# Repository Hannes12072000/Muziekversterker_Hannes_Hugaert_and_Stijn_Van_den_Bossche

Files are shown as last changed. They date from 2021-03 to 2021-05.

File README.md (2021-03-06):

# Muziekversterker_Hannes_Hugaert_and_Stijn_Van_den_bossche
 
onderwerp:  Touch muziekversterker
naam:   Hannes Hugaert & Stijn Van den bossche

Korte beschrijving:
Wij gaan een muziekversterker maken die voorzien is van 2 channels en een microfoon. Op deze versterker kunnen we de tonen regelen (treble, medium en bass) maar we kunnen ook het volume regelen. Onze sliders zijn geen gewone mechanische sliders, we voorzien touchpads als sliders. Om feedback over het volume en de tonen te geven, voorzien we ledjes naast de touchpads om het huidige niveau weer te geven.

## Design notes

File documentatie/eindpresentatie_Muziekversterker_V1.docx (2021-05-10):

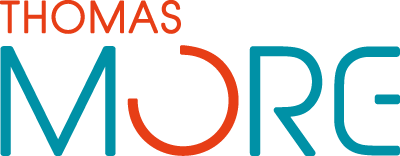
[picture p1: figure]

Thomas More

Campus De Nayer

Jan De Nayerlaan 5

2860 Sint-Katelijne-Waver

Tel. (015) 31 69 44

Practice Enterprise Electronics

Schooljaar 2020-2021

NAAM: Hannes Hugaert & Stijn Van den bossche

#### ONDERWERP: Muziekversterker

AFDELING: Elektronica – Embedded Hardware 2 | 2EE2

Elektronica – Embedded Software 2 |

# 1. Woord vooraf

Wij gaan een muziekversterker maken die voorzien is van 2 input-channels en een microfoon. Op deze versterker kunnen we de verschillende tonen regelen per kanaal (treble, medium en bass), alsook het volume van deze kanalen. Hier bovenop voorzien we ook een ‘balans’, om te regelen in welke mate beide kanalen worden doorgegeven, en ook een ‘master output’. Hiermee kiezen we het volume van het uiteindelijke uitgangssignaal. Onze sliders zijn niet de gewone, mechanische sliders die meestal aanwezig zijn op een mengpaneel, wij voorzien touchpads als sliders. Om ook het volume of de verschillende tonen te visualiseren, voorzien we ledjes naast de touchpads.

# 2. Hardware

## 1.1. Blokschema

Audio output: staat voor de luidsprekers die aan de uitgang komen, dezen moeten voorzien worden van een inwendige versterking omdat onze versterker amper stroom zal hebben aan de uitgang.

2 AUDIO inputs: Wij hebben ons mengpaneel voorzien van 2 inputkanalen waar wij muziek op kunnen laten spelen (via AUX).

Ook kunnen we op lijn 1 eventueel een microfoon steken, zodat over de muziek heen te praten is, indien gewenst.

5V DC: micro USB, dit is de voeding voor de versterker.

5V DC naar 3.3 V DC: dit is de naam van de component 173950336, het is een step-down die 5V omzet naar +3.3 V DC. Dit wordt gebruikt om de microcontroller en de capacitieve touchsensor te voeden.

Microcontroller: De gebruikte microcontroller is een STM32F411CEU7, om hiermee te communiceren wordt een st-link V2 gebruikt, zodat we deze kunnen programmeren. Onze Microcontroller is van de SMT32F4x familie en die wordt gevoed met 3.3V en we willen ook ongeveer 40 I/O. En onze heeft er 49 dus dat is zeer goed.

8-digit LED displaydrivers: deze chip heet MAX7219CNG+. Dit is een chip om 8 segment displays aan te sturen, wij gebruiken een ‘matrix’ van leds, waarvoor deze drivers ook te gebruiken zijn.

Dit hoort samen

LED’s: Dezen laten het huidig geselecteerde volume en de stand van de verschillende tonen zien. Er zijn 132 leds, om dit genoeg in detail weer te geven.

Capacitieve touchsensor: deze sensor heet de MTCH6301-I_ML, het leest capacitieve aanrakingen afkomstig van de touchpads, zet deze om naar coordinaten, en verstuurt deze via een I²C signaal. Deze waardes worden wel opnieuw geïnterpreteerd, aangezien de gebruikte touchpads niet allemaal samen staan, en het dus niet één compleet vlak is. We hebben ook gekozen voor capacitief omdat dat geen corrosie geeft op de sliders.

Dit hoort samen

Touchpads: dit zijn geleiders die op een print door middel van aanraking een capacitief signaal doorsturen. Deze touchpads dienen als sliders van het mengpaneel. Ze zijn zelf ontworpen, om hier een grote kost uit te sparen, en zelf de vorm en grootte te kunnen bepalen.

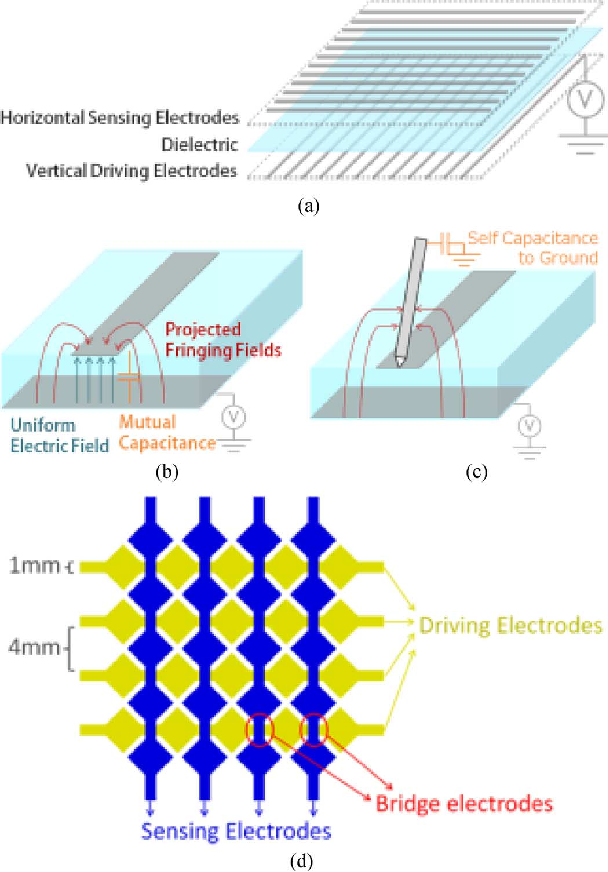
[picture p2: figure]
Figure 1 from An Analysis of Electrode Patterns in Capacitive Touch Screen Panels | Semantic Scholar

Digitale potentiometers: onze potentiometers hebben de naam AD5204BRUZ10-REEL7. Tijdens het kiezen hoe we de potentiometers zouden aansturen, bleek dat het makkelijker zou zijn om digitaal gestuurde potentiometers te werken, anders hadden we zelf mechanische sliders moeten voorzien, wat veel duurder ging uitkomen.

Versterking: We gebruiken de opamps LM324A. Ze vormen de basis van de versterkingcircuits.

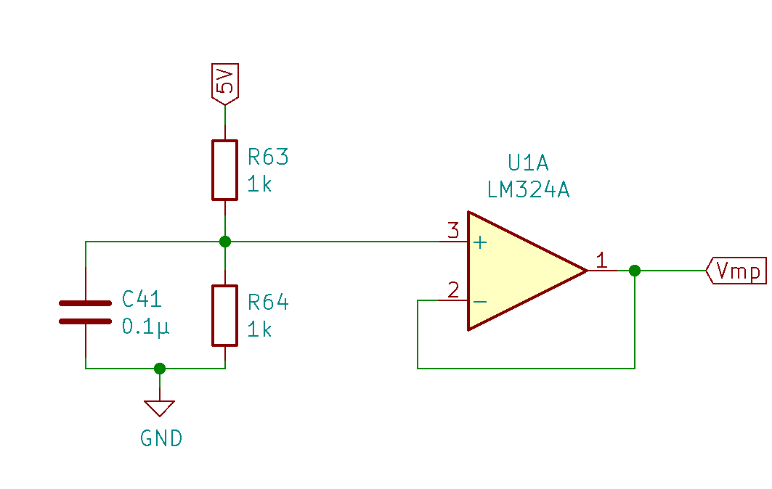
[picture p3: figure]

Virtuele grond: Omdat we problemen hadden met de potentiometers en zo in de schakeling hebben we een virtueel middelpunt moeten maken dit is aan de hand van een spanningsdeler een opamp.

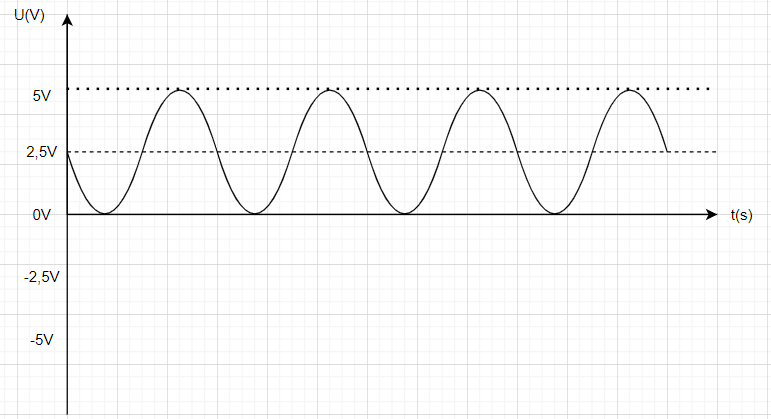
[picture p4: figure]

5V/2 =2,5V is dus gewoon een spanningsdeller gedeeld door 2 waardoor we gewoon twee gelijke weerstanden moeten nemen. De docent stelde ons voor om 1kΩ weerstanden te gebruiken.

We willen dat het nulpunt op 2,5 V ligt. Zodat we de opamps kunnen fluctueren tussen 0V en 5V. Zo hebben we zekerheden met het signaal en de potentiometers en dan kunnen we gewoon de 5V van de usb gebruiken wat heel handig. Anders moesten we de spanning verlagen van 5V naar 2,5V en ook naar -2,5V en dat gaat ons veel meer kosten dan dat we het middelpunt gaan verleggen. We blijven ook het zelfde uitgangssignaal horen.

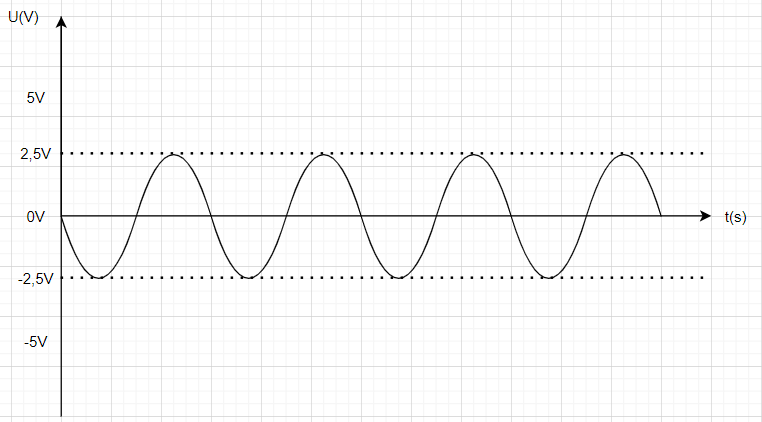
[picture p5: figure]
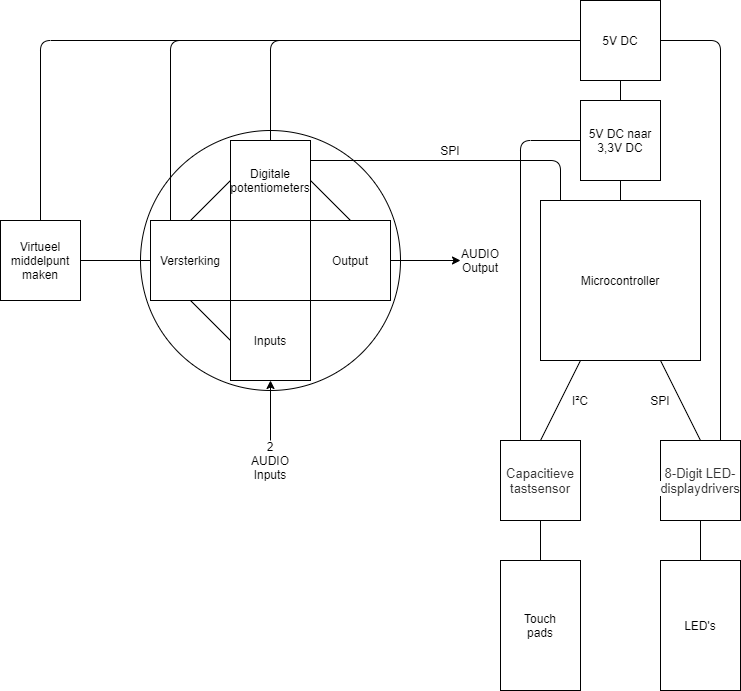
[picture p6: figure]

## 1.2. Schema

Touchpad: Dit is het symbool van onze sliders, deze hebbe zelf ontworpen om dat we deze wouden verwerken in onze PCB, hier hebbe we heel veel moeten voor opzoeken want zoe een raster van een slider moet aan een bepaalde afmetingen voldoen zodat het zeker voldoende afstand heeft van el vlakje en ook een deftige connectie kunt maken als je met je vinger op de touchpad komt.

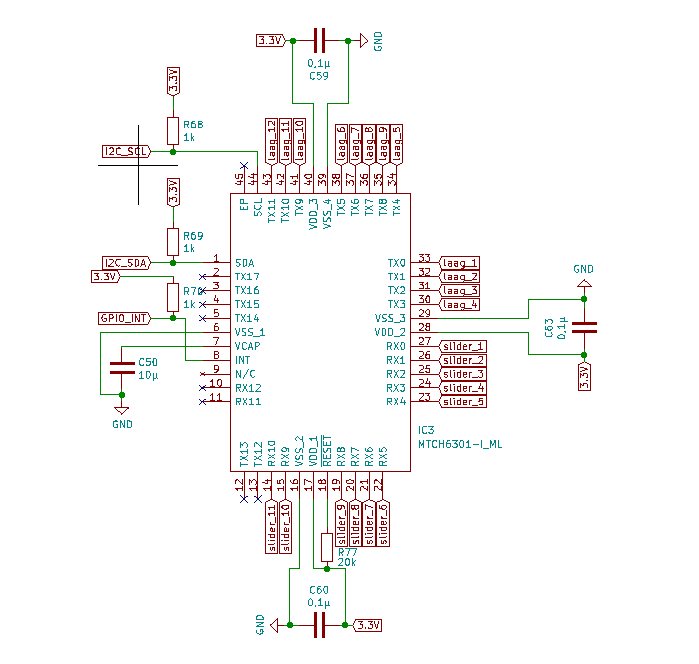
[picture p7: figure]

MTCH6301-I_ML: dit is de IC die de signalen op de touchpad’s uitleest en om zet in data die over I²C naar de microcontroller gaat.

Deze condensatoren zorgen er voor dat er geen storing op de 3.3V zit, zo blijf je een ongeveer een mooie rechte 3.3V hebben.

Als de interrupt van de microcontroller spanning verliest of de spanning is hoger dan 3.3V zorgt de pull up weerstand dat de nodige 3.3V aan de IC komt.

De RESET moet laag zijn om een zichzelf te resetten maar wij willen niet dat dat we deze chip resetten dus daarom zetten we ze aan de 3.3V zodat de chip zijn data niet verliest door de reset.

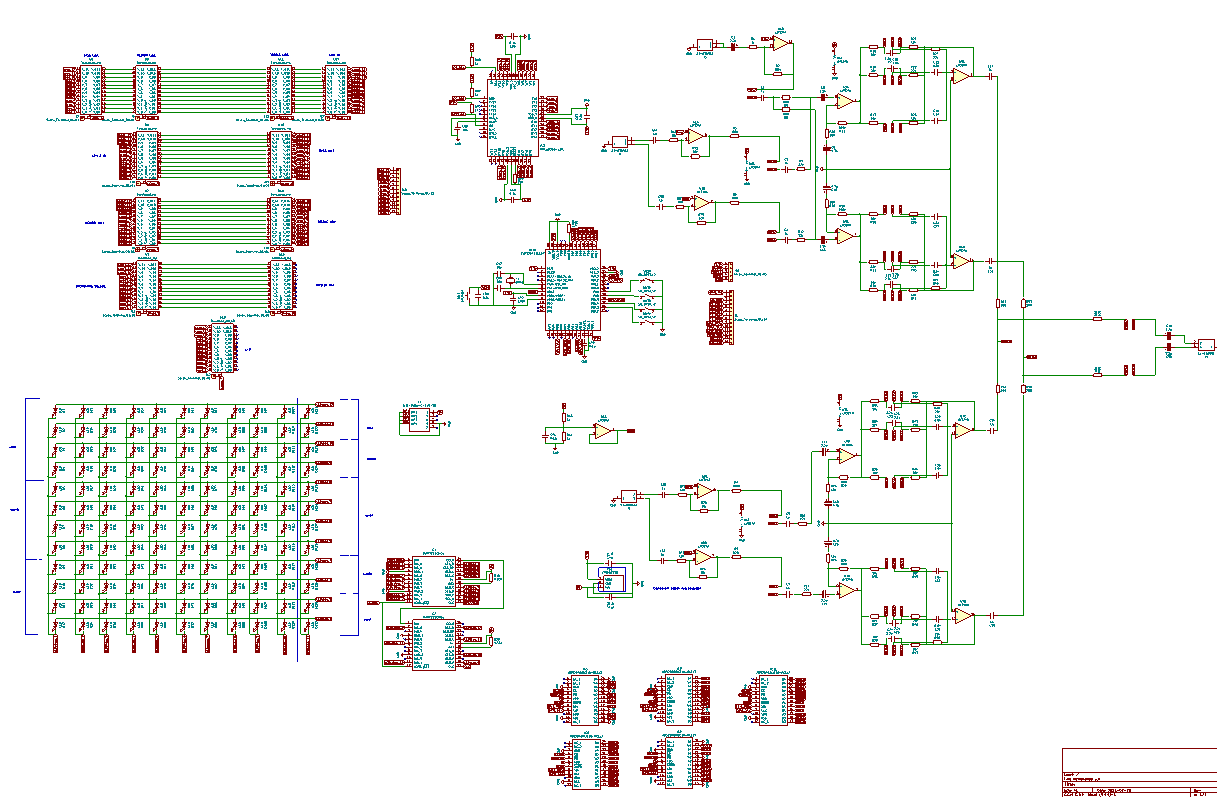
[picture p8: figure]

Micro usb

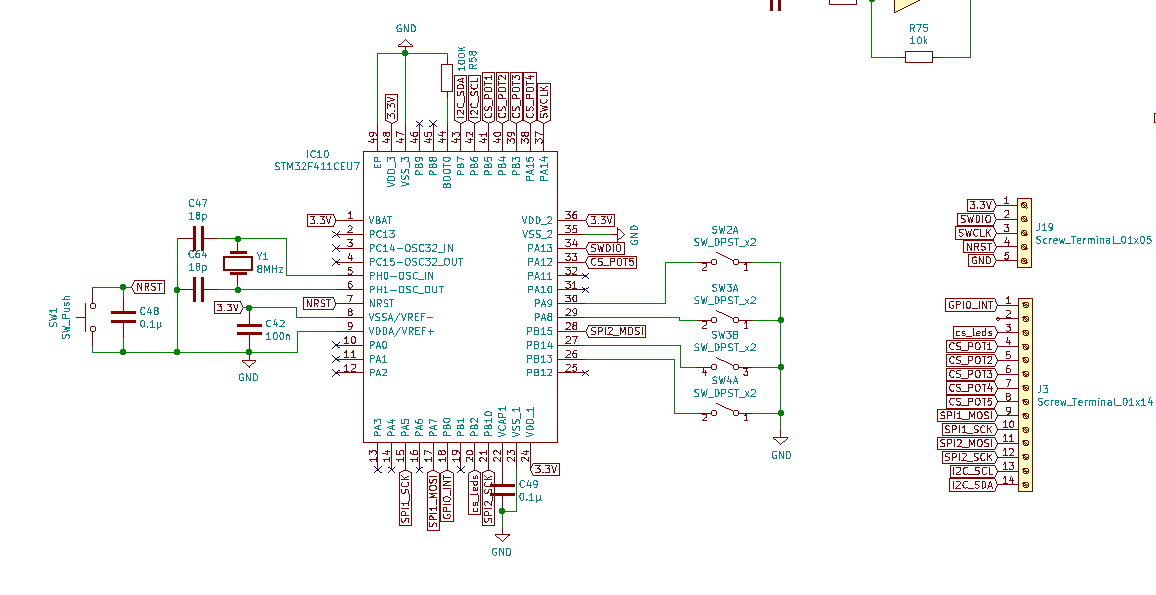
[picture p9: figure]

STM32F411CEU7: Deze microcontroller is voorzien van 512KB Flash en 128 KB RAM en is een ARM cortex die op 32 bit werkt. Deze microcontroller is voorzien van 49 pinnen wat ruim genoeg is voor onze uitwerking. Deze microcontroller moet gevoed worden op een spanning tussen 1.7 en 3.6 dus hebben we gekozen voor het midden ongeveer 3.3V.

We hebben ons bord voorzien van externe pinnen stel dat er iet met onze microcontroller gebeurd of we willen de signalen mooi en gemakkelijk willen lezen kunnen we deze uitlezen op de ze pinnen.

Wij hebben een reset knop voorzien op de microcontroller zodat we altijd op nieuw het programma kunnen laten afspelen, stel dat er een is kunnen we dit direct uitlezen door de pinnen die hierboven vermeld worden. De reset moet voor zien worden van condensator zodat we geen bounce krijgen zie oscillatie.

De microcontroller moet een kristal oscillatie hebben tussen 4 a 26 MHz. Wij hebben de onze voorzien met een kristal van 8 MHz, waardoor deze perfect tussen 4 a 26 MHz oscillatie past die onze microcontroller nodig heeft.

Op de microcontroller zijn er twee poorten voorzien voor een oscillatie en wij hebben gekozen voor PH0 en PH1 omdat de andere een oscillatie maar van 32 kHz max mag voorzien en dat met het gebruik van een RTC, deze bevind zich op pinnen PC14 en PC15. Door dat we een de kristal gebruiken krijgen we een interne klok van 16 MHZ en als we de RTC gingen gebruiken was het een interne klok van 32 kHz.

## 1.2.1. Communicaties

UART

UART hebben we voorzien omdat we ons programma moeten inlezen in de microcontroller. Aan de pinnen van de UART voorzien we een “USB to ttl” zodat we seriële communicatie van de usb op die PCB naar UART kunnen omzetten. Dit kan de microcontroller perfect uitlezen.

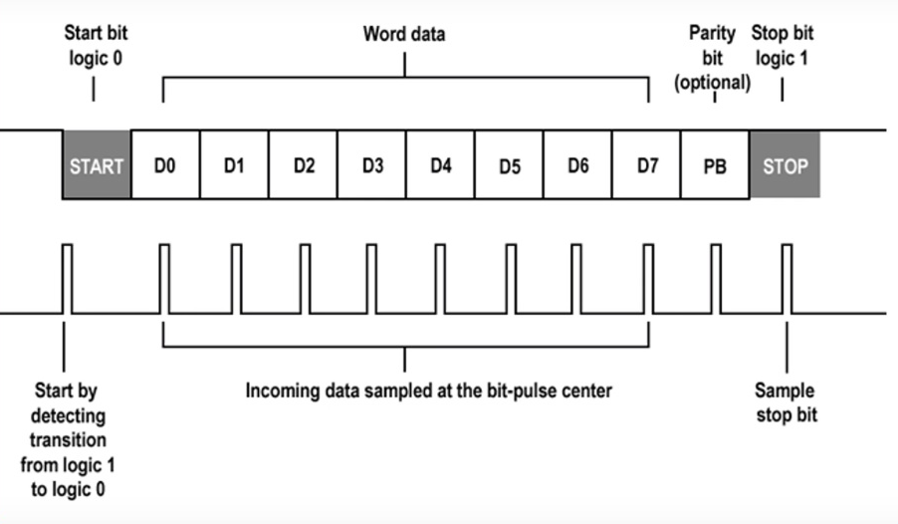
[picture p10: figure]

Binnen komende data

CLK die hoog word

als je data moet

uitlezen

Tijd voor uitlezing: 1.5 bit, 1 bit, …..(de rest is ook 1 bit)

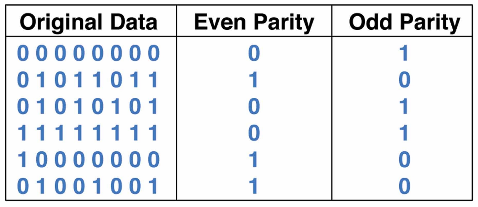
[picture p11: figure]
Parity Checkers and Generators Selection Guide | Engineering360

De data van UART word altijd maar uitgelezen als de binnenkomende data eerst laag wordt dit is de start bit en dan heb je de 8 bit of 1byte die zowel hoog of laag kunnen zij maar natuurlijk niet tegelijk natuurlijk. Na de 8 bit komt de parity bit deze is er niet altijd maar het detecteert altijd 1 fout en zegt of het oneven is of even aan de hand van een 1(even) of 0(oneven) te zetten in deze bit. Zoals deze teken hiernaast. De laatste bit moet terug hoog worden bij de UART dit wordt de stop bit genoemd en dan stopt de TX met uitlezen.

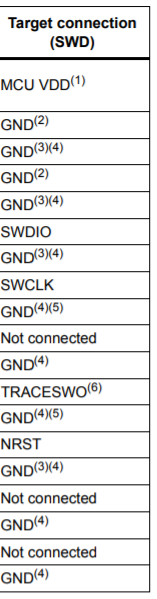
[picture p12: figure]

Doordat we de STM32F411CEU7 kunnen we niet programmeren met de “USB to ttl” dus dan programmeren we niet met het protocol Uart maar wel met seriële communicatie. De datasheet van de st link V2 verwijst er naar om de pinnen zo aan te sluiten zoals op de op de tabel en tekening hieronder.

2. Maak verbinding met GND voor ruisonderdrukking op het lint.

3. Alleen beschikbaar op ST-LINK / V2, niet aangesloten op ST-LINK / V2-ISOL.

4. Ten minste één van deze pennen moet met de grond worden verbonden voor correct gedrag (ze allemaal verbinden is

aanbevolen).

5. GND op ST-LINK / V2, gebruikt door SWIM op ST-LINK / V2-ISOL

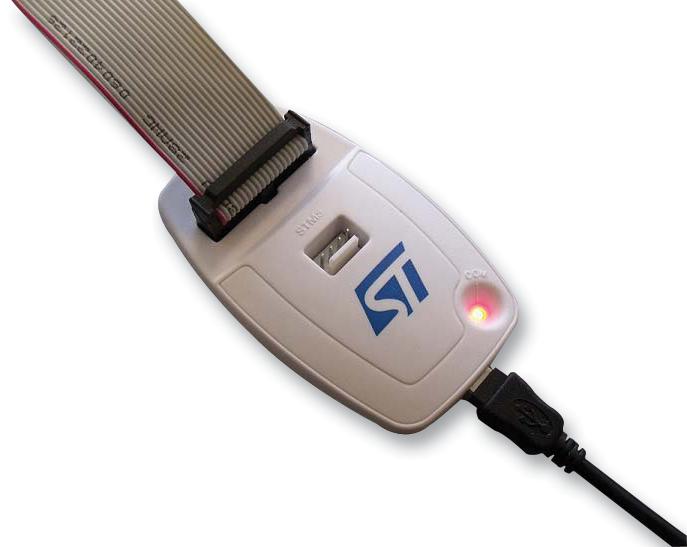
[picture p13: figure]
ST-LINK/V2 - Stmicroelectronics - In Circuit Debugger/Programmer, For STM8 & STM32, SWIM and JTAG Serial Wire Debugging Interfaces

De pin SWCLK van de ST link V2 moeten op pin PA14 van de STM32F411CEU7 komen. De pin SWDIO van de ST link V2 moeten op pin PA13 van de STM32F411CEU7 komen. Stel deze in op de microcontroller en dan kan je beginnen met programmeren van de microcontroller op ons mengpaneel.

SPI

Als de Chip Select (CS) een laag signaal heeft en die doorstuurt naar een bepaalde slave, want wij gebruiken er meerdere. Zo kan de data alleen naar de bepaalde slave’s verzonden worden die een laag CS binnen krijgen.

- Digitale potentiometer: Als je CS laag gemaakt hebt kan je de 16 bit data beginnen inlezen. De digitale potentiometers beginnen de adressen en de data in te lezen als het CLK hoog is. Als alle adressen en data is ingelezen moet CS teru goog worden en zal de weerstands waarde van de poteniometer veranderen.
- 8-Digit LED Display Driver: Hier gebeurt exact het zelfde als bij de digitale potentiometer, behalve dat als de data wordt ingelezen en iets nadat de CLK laag is verander de output.

I²C

De IC voor onze touchpad’s worden aangestuurd met I²C. Dit protocol wordt over 2 lijnen gestuurd de lijn SDA (data line) en SCL (clock line). De lijn data is geen data die binnenkomt op de chip maar toont aan wat voor data er binnenkomt.

Start: De chip begint te starten met lezen van data als de SDA lag wordt en SCL hoog is dit is dan de start bit, daarna moet SCL eens laag worden en dan kan het data beginnen ingelezen worden. Per keer dat SCL hoog wordt de data op SDA uitgelezen.

Read: De eerste data dat binnen gelezen wordt is het adres + een read bit zodat de master zegt dat hij de data wilt uitlezen. Als dit gebeurd is zal de INT laag worden zodat het kan beginnen met de data uit te lezen, als INT hoog stond wil dat zeggen dat het adres niet machte.

Master read

Write: De eerste data dat binnen gelezen wordt is het adres + een write bit zodat de master zegt dat hij de data wilt uitlezen. De INT blijft hier laag zodat het altijd kan dat verzenden.

Stop: De stop bit wordt aangeduid als de SCL al eventjes hoog is en daarna SDA hoog wordt.

## 1.2.2. Spanningsregelaars

173950336: is een Step Down die 5V DC omzet naar 3,3V DC en heeft een uitgangsstroom van 500 mA.

De condensatoren dienen voor spanningen af te vlakken zo zitten we zonder ruis op de beide spanningen.

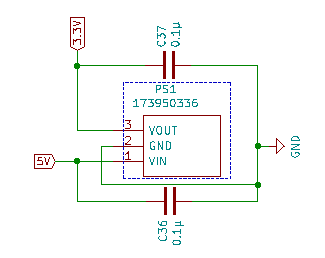
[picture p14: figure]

## 1.2.3. Digitale potentiometer(AD5204BRUZ10-REEL7)

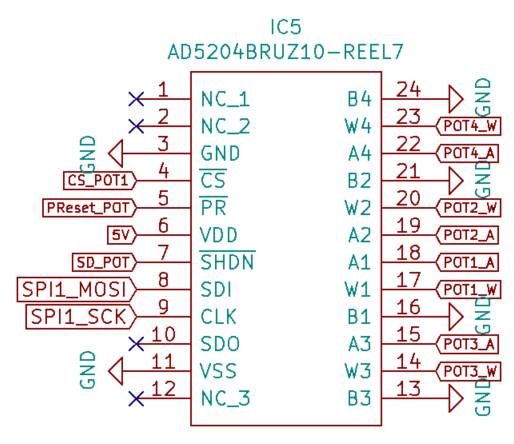
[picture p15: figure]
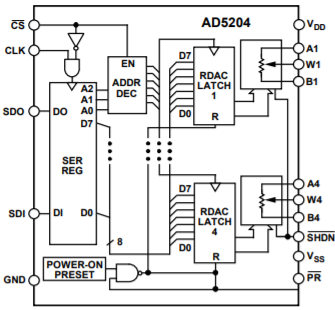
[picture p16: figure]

CS: Zorgt er voor dat dat de waardes maar gelezen wordt als deze uitgelezen worden als deze laag is.

CLK: Als de Clock hoog is zal de data doorgegeven worden in het shiftregister. Door de AND poort in de chip zorgt de CS en de clock er voor de data wordt door gegeven en uitgelezen kan worden.

SDI: Hier worden alle bits ingelezen die je doorstuurt op deze pin. Het shiftregister leest een serieel signaal in de eerste 3 bits zijn de adres bits de rest zijn de 8 data bits (of 1 byte). Als alle data is uitgelezen en CS wordt terug hoof zal de data uitgelezen worden.

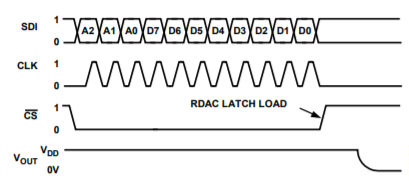
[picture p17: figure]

SDO: gaan wij niet gebruiken omdat je dan dn bv meerdere potentiometers er kunt aan hangen en dan heb je een hele slinger van componenten die in serie aan elkaar hangen. Maar wij willen dat als SPI programmeren deze potentiometers wat natuurlijk ook zeker kan want als je deze potentiometers hebt met 6 potentiometers dan heb je deze pin niet maar voor de rest is alles het zelfde dus je kan dit perfect als SPI protocol programmeren.

An, Wn, Bn: zijn de pinnen van de potentiometer.

PR: Zorgt ervoor dat de waardes resetten als het laag is en terug op de begin waarden komen te staan.

SHDN: is de shutdown van de potentiometers zelf. Het zet de potentiometers af als het signaal laag is.

Vdd en Vss: De Vdd is de spanning die de potentiometer gaat voeden en is ook de spanning die er maximum door de potentiometers mag vloeien en Vss is de minimum spanning die er door de potentiometers mag vloeien. Maar waarde Vdd moet tussen de 3V a 5V DC vloeien en Vss moet tussen de 0V a -2,7V DC vloeien en het verschil tussen Vdd + Vss mag niet hoger zijn dan 5,5V.

## 1.2.4. 8 digit LED display driver (MAX7219CNG+)

Deze IC wordt vak gebruik voor 7 segment displays, maar je kan het ook voor andere displays of matrixen gebruiken. Zo hebben wij zelf onze LED matrix zelf gemaakt om zo de niveaus aan te duiden want zo kan je zien op welk niveau de potentiometers zich bevinden. Je moet de anodes en de kathodes samen steken om een matrix te maken.

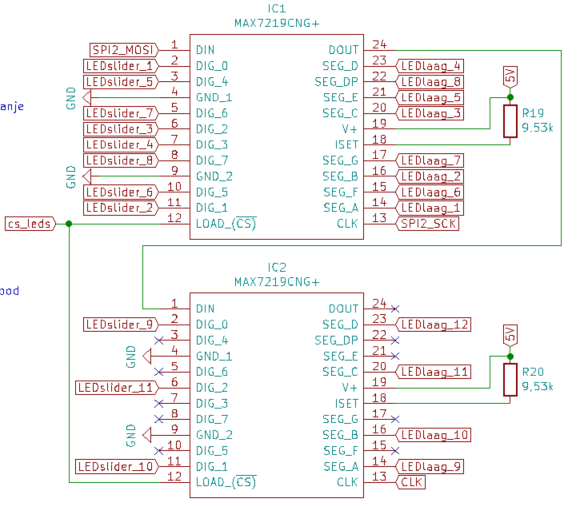
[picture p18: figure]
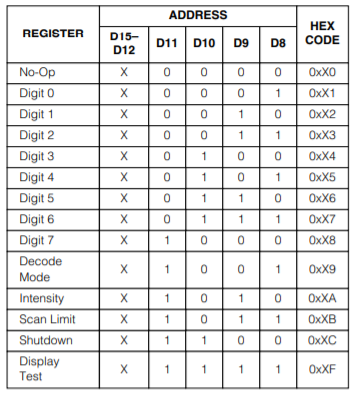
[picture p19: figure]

De communicatie naar deze chip werkt het zelfde als de potentiometers, er moeten 4 bits voorzien worden om adressen door te geven dit is bit 11, 10 , 9 en 8. Daarna heb je ook de data die verzend we met 8 bit dit is bit 7(MSB) tot bit 0(LSB).

Elke bit voor de adressen heeft een eigen functie zo zie je in de tabel hieronder welke binaire waarde voor welke functie gebruikt wordt. Zo zie je ook dat de eerste 4bit geen functie heeft D15 tot D12.

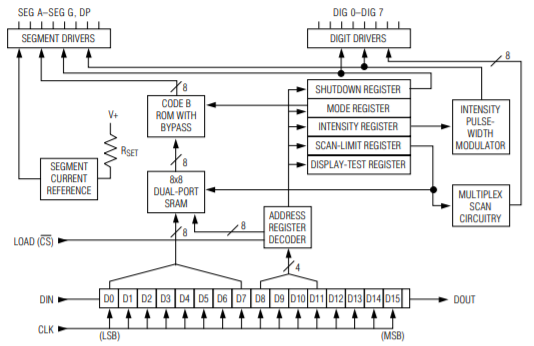
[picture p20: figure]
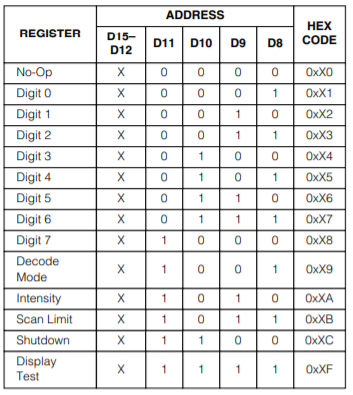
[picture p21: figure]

De tabel hierboven verteld over de digits. De onderste tabel is voor de segmenten. Zo laat de tabel zien dat niet alle data bruikbaar is om de segmenten te doen op te lichten. Natuurlijk zou deze code niet goed gaan bij een 7 segment display maar daar hebben ze een andere codering voor. Maar die hebben wij niet nodig, wij gebruiken deze code.

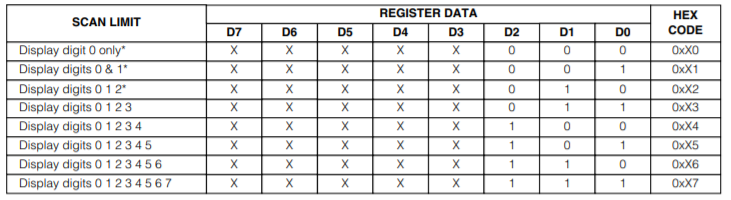
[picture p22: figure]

Onze led matrix is voorzien van 132 LED’s dus komen we met 1 8digit-LED display driver niet toe dus moesten we dit met 2 8digit-LED display driver doen. Deze kunnen we achter elkaar zetten zodat we via seriële communicatie kunnen doorlussen. Omdat wij ook verschillende kleuren gebruiken om aan te duiden op welke volume we zitten hebben we gekozen voor de kleuren groen oranje en rood te gebruiken.

Groen betekent dat het geluid of regel circuit nog rustig staat.

Oranje betekent dat het volume of regel circuit al luider en zwaarder wordt.

Rood betekent dat het volume of regel circuit op het luidste en zwaarste staat.

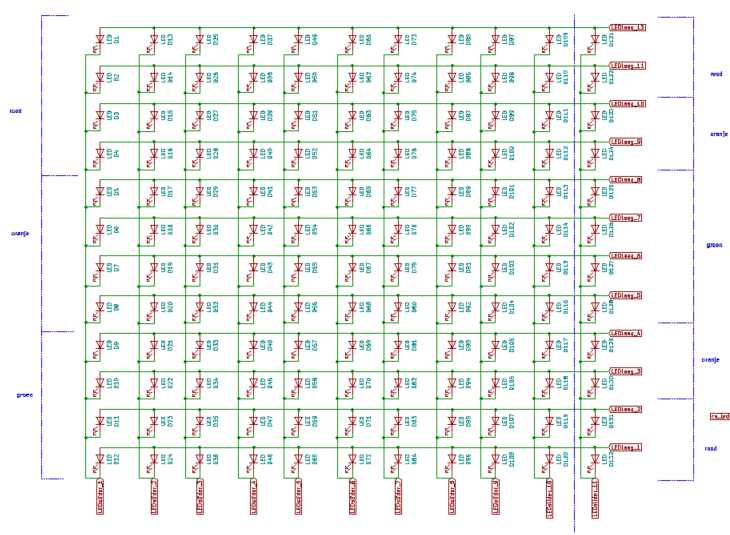
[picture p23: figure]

Elke LEDslider heeft zijn eigen slider waar het naast komt te staan de leds staan mooi allemaal geschikt naast de sliders zoals ze hierboven staan. Door het schema te zien van hierboven kan je op de PCB zien welke LEDslider lijn voor welke slider dient.

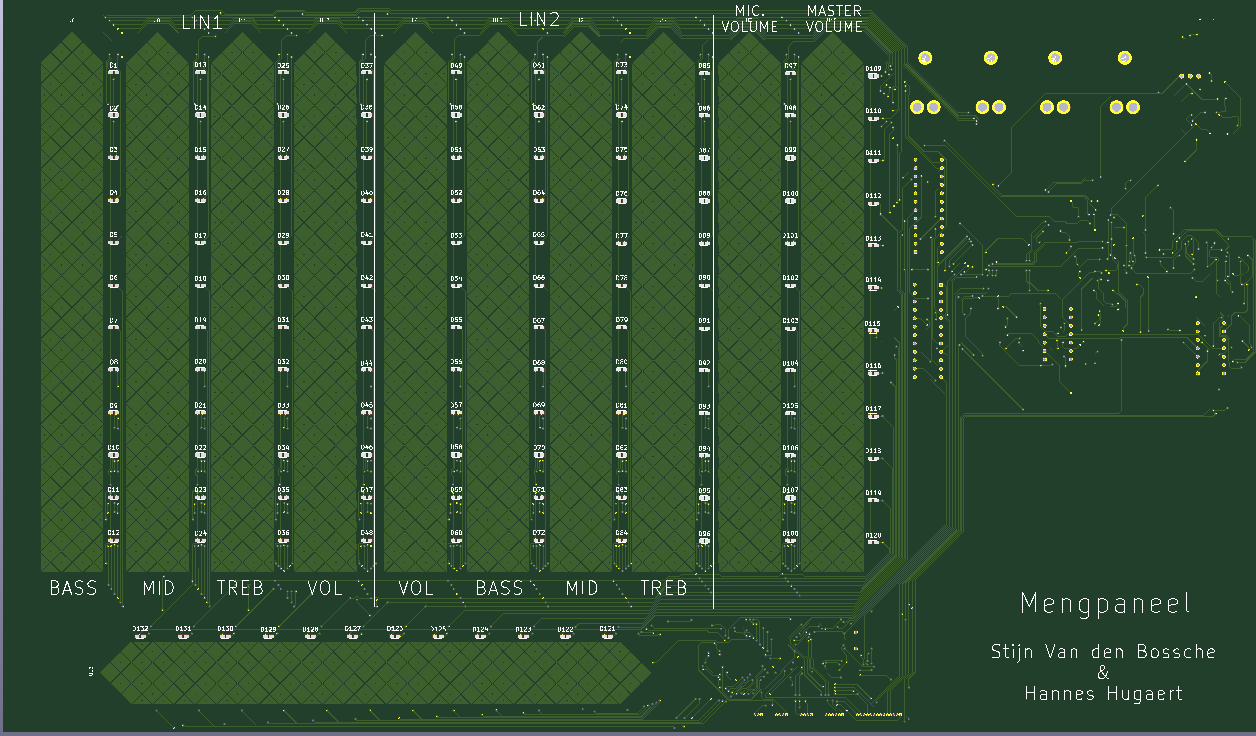
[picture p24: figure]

## 1.2.5. Versterking

Onze PCB is ook nog voorzien van een volledig circuit om de volumes, Bassen, mediums en trables te regelen op 2 lijnen waar muziek op komt en ook op lijn 1 waart je ook kan opteren om een microfoon te voorzien. Ik ga aan de hand van grafieken laten zien hoe elke versterking werkt laten zien.

Dit laat ik zien in het hoofdstuk PSpise.

## 1.3. PSpise

## 1.4. Bestukkingsplan

## 1.5. PCB lay-out

## 1.6. Datasheets

# 3. Software

## 1.1. Flowchart software

## 1.2. Listing (de code)

# 4. Bediening handleiding

# 5. Besluit

# 6. Opgezochte sites

Pagina 2 van 2

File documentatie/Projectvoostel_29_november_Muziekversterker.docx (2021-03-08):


Thomas More

Campus De Nayer

Jan De Nayerlaan 5

2860 Sint-Katelijne-Waver

Tel. (015) 31 69 44

Practice Enterprise Electronics

Schooljaar 2020-2021

NAAM: Hannes Hugaert & Stijn Van den Bossche

#### ONDERWERP: Muziekversterker

AFDELING: Elektronica – Embedded Hardware 2 | 2EE2

Elektronica – Embedded Software 2 |

# 1. Projectvoorstel

## 1.1. Namen

- Hannes Hugaert
- Stijn Van den Bossche

## 1.2. Titel

Touch muziekversterker

## 1.3. Korte beschrijving

Wij gaan een muziekversterker maken die voorzien is van 2 channels en een microfoon. Op deze versterker kunnen we de tonen regelen (trable, medium en bass) maar we kunnen ook het volume regelen. Onze sliders zijn niet de gewone die we tegenkomen op een gewone versterker maar wij gaan onze voorzien van touchpad’s als sliders. Om ook de weergave van het volume of de tonnen te laten zien voorzien we ledjes naast de touchpad’s om die verandering te kunnen waarnemen.

## 1.4. Blokdiagram

BOX: staat voor de boxen die die de uitgang komen.

5V DC USB: dit is onze input voor onze versterker te voeden.

5V omvormen naar +15V en -15V: hier hebben we een step-up voorzien die onze 5V omzet naar +15 V en met de die +15V kunnen we een -15V maken. Dit dient voor onze opamps te voorzien van de nodige spanning.

5V omvormen naar 3.3V: hier verlagen we de spanning van 5 V naar 3.3 V met een spanningsregelaar, dit is voor onze CPU en STM32F103CBT6 voeding te geven.

STM32F103CBT6: met deze kunnen we communiceren van de USB poort naar de CPU. Want onze CPU kan geen rechtstreekse signalen uitlezen van de computer daar is er geen poort voor voorzien.

CPU: onze CPU is van de SMT32F4x familie en die wordt gevoed met 3.3V en we willen ook ongeveer 50 I/O.

LED’s: deze led’s tonen aan hoe luid en hoe hoog of laag onze tonen zijn geregeld.

Touchpad’s: dit zijn geleiders die op een print door middel van aanraking een capacitief signaal doorsturen. Deze touchpad’s worden onze sliders van ons paneel. Deze gaan wij zelf maken zo besparen we 3 euro per slider uit en kunnen we onze vorm en grote zelf bepalen.

Sturen van weerstanden voor het geluid: wij hebben gezocht naar een oplossing om onze potentiometers te kunnen sturen. Zo kwamen

we uit op gestuurde potentiometers.

Dit hoort samen

Versterken muziek signaal: wij gaan onze muziek versterken met opamps en ook nog met de nodige andere componenten.

Opamps: Dit zijn gewoon onze opamps.

De AUX en microfoon poorten: dit zijn onze ingangspoort die je kan inpluggen meteen een jacket(AUX).


## 1.5. Component/tool keuze

We wouden zeker met een CPU van de familie STM32Fx dus hebben we al in de reeks van SMT32F4x welke precies in die reeks weten we nog niet exact omdat we nog in de bouw fase zitten van de print en dan kan er nog wel wat veranderen.

## 1.6. Marktonderzoek

Op de markt vinden we heel veel verschillende muziekversterkers. Je kan ze ook vaak met een mengpaneel te samen vinden. Er zijn maar heel weinig versterkers die een touchpad of touchscreen sliders hebben. De meeste zijn nog altijd met de gewone sliders. Wij willen dus een touch muziekversterker maken en uitzoeken waarom touch ook niet goed zou zijn en de verschillen tussen de gewone versterkers en de onze.

## 1.7. Resultaat technologie verkenning

We zijn momenteel nog altijd op zoek naar onze CPU momenteel hebben we de STM32F413RGT6 omdat deze momenteel voldoet aan onze eisen zoals 50 I/O, voldoende geheugen (even veel geheugen als ons bordje van Embedded Systems).

Doordat we met touchpad’s werken poesten we sliders vinden die we kunne met onze CPU. Zo kwamen we uit op onze AD5290YRMZ10-R7 dit is een gestuurde potentiometer.

## 1.8. Budget raming

Ons spanningsgedeelte zal rond kost 3 euro kosten, het hele versterkingsgedeelte + jackets zal rond de 112 euro kosten, De CPU kost ongeveer 8 euro en met de led’s gaat het 4 euro kosten.

Als dat alles samen voegt gaat dat ongeveer 140 euro kosten + pcb.

Pagina 2 van 2

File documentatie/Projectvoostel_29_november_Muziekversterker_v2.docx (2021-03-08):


Thomas More

Campus De Nayer

Jan De Nayerlaan 5

2860 Sint-Katelijne-Waver

Tel. (015) 31 69 44

Practice Enterprise Electronics

Schooljaar 2020-2021

NAAM: Hannes Hugaert & Stijn Van den bossche

#### ONDERWERP: Muziekversterker

AFDELING: Elektronica – Embedded Hardware 2 | 2EE2

Elektronica – Embedded Software 2 |

# 1. Projectvoorstel

## 1.1. Titel

Muziekversterker en mengpaneel met touchcontacten.

## 1.2. Korte beschrijving

Wij gaan een muziekversterker maken die voorzien is van 2 inputchannels en een microfoon. Via deze versterker regelen we in welke mate de inputkanalen worden doorgelaten, zowel op het vlak van volume als welke specifieke tonen (bas, middle en treble). Om dezen te regelen zouden we sliders gebruiken, meer specifiek een soort van touchpad waarover met de vinger kan geschoven worden. Deze waarden worden dan weergegeven met behulp van ledjes naast de touchpads. Specifieker zouden er per kanaal dus 3 touchpads zijn voor de tonen te regelen, en één voor het volume hiervan te regelen. Verder zouden we ook nog een extra slider voorzien waarmee kan gekozen worden in welke mate de twee kanalen doorkomen, m.a.w. de verhouding tussen de twee kanalen. Voor de microfooninput zou er enkel een slider voorzien worden om het volume te regelen. Dit zou dus neerkomen op een totaal van ongeveer 10 sliders.

## 1.3. Blokdiagram

Zoals te zien op het blokdiagram op volgende pagina is het de bedoeling om de waarden van de touchpads in te lezen in de microcontroller, en aan de hand van deze waarden de nodige weerstanden aan te passen die het geluid in realtime versterken/verzwakken. Ook word aan de hand van de ingelezen waardes een feedback gegeven aan de hand van ledjes.

BOX: Staat voor de boxen die kunnen verbonden worden om het geluid mee af te spelen. Dit zou voorzien zijn via aux-kabel.

5V DC USB: dit is onze input voor onze versterker te voeden.

5V omvormen naar +15V en -15V: Hier hebben we een step-up voorzien die onze 5V omzet naar +15 V en -15V. Dit dient om onze opamps te voorzien van de nodige spanning.

5V omvormen naar 3.3V: Hier verlagen we de spanning van 5 V naar 3.3 V met een spanningsregelaar, om de microcontroller te voeden. Indien een andere keuze wordt gemaakt kan dit aangepast worden aan de specificaties van de microcontroller.

Dongle: Hiermee zouden we proberen programmeren naar de microcontroller. Zodat we na het verwijderen van de dongle, de microcontroller niet meer kunnen programmeren. Zonder de dongle kunnen we het niet programmeren.

LED’s: Deze led’s tonen aan hoe luid en hoe hoog of laag onze tonen zijn geregeld.

Touchpad’s: Dit zijn geleiders die op een print door middel van aanraking een waarde doorsturen. Dit zou gebeuren met kleine vlakjes waarvan de capacitieve waarde veranderd. Deze touchpads worden de sliders van ons paneel. Deze gaan wij zelf maken op de PCB.

Sturen van weerstanden voor het geluid: We hebben gezocht naar een oplossing om onze potentiometers te kunnen sturen. Zo kwamen we uit op gestuurde potentiometers.

Versterken muziek signaal: wij gaan onze muziek versterken met opamps en ook nog met de nodige andere componenten.

Opamps: Deze gebruiken we om de signalen te versterken.


De AUX en microfoon poorten: Dit zijn de ingangspoorten die je kan inpluggen meteen een jack (AUX).

## 1.4. Component/tool keuze

We zouden zeker een microcontroller van da familie STM32F gebruiken, onze voorlopige keuze ligt op de STM32F103CBT6. Deze keuze kan nog veranderen afhankelijk van nodige specificaties of problemen die we ondervinden met de keuze.

## 1.5. Marktonderzoek

Op de markt vinden we heel veel verschillende muziekversterkers, vaak ook samen met een mengpaneel. Er zijn echter niet veel met touchpads, de meesten hebben fysieke sliders. Wij willen dus een maken met touchpaneeltjes, om te proberen uit te zoeken wat de voor- en/of nadelen zijn hiervan qua gebruiksvriendelijkheid.

## 1.6. Resultaat technologie verkenning

We zijn momenteel nog aan het zoeken naar mogelijke alternatieven voor microcontroller, omdat we nog niet helemaal zeker zijn van welke specificaties er exact nodig zijn. Omdat we via de touchpanelen enkel een waarde inlezen in de microcontroller, hebben we ook digitaal stuurbare potentiometers nodig. Zo kwamen we uit op AD5290YRMZ10-R7.

## 1.7. Budget raming

Ons spanningsgedeelte zal rond kost 3 euro kosten, het hele versterkingsgedeelte + jackets zal rond de 112 euro kosten, De microcontroller kost ongeveer 8 euro en de leds zouden ongeveer 8 euro kosten.

Als we alles optellen zou dit neerkomen op ongeveer 140 euro + pcb.

Pagina 2 van 2

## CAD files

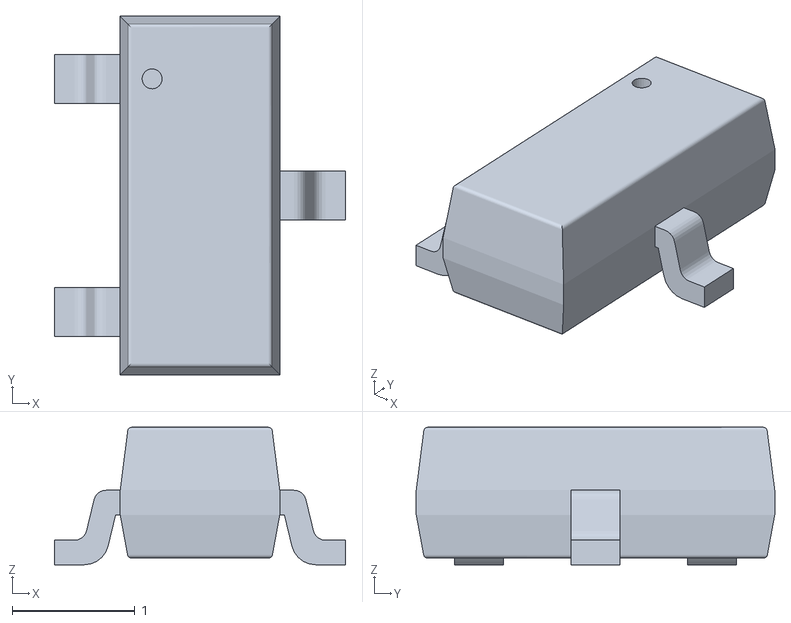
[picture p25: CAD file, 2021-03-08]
KICad_Libraries/LM3480IM3-3.3_NOPB.stl
2.37 x 2.92 x 1.12

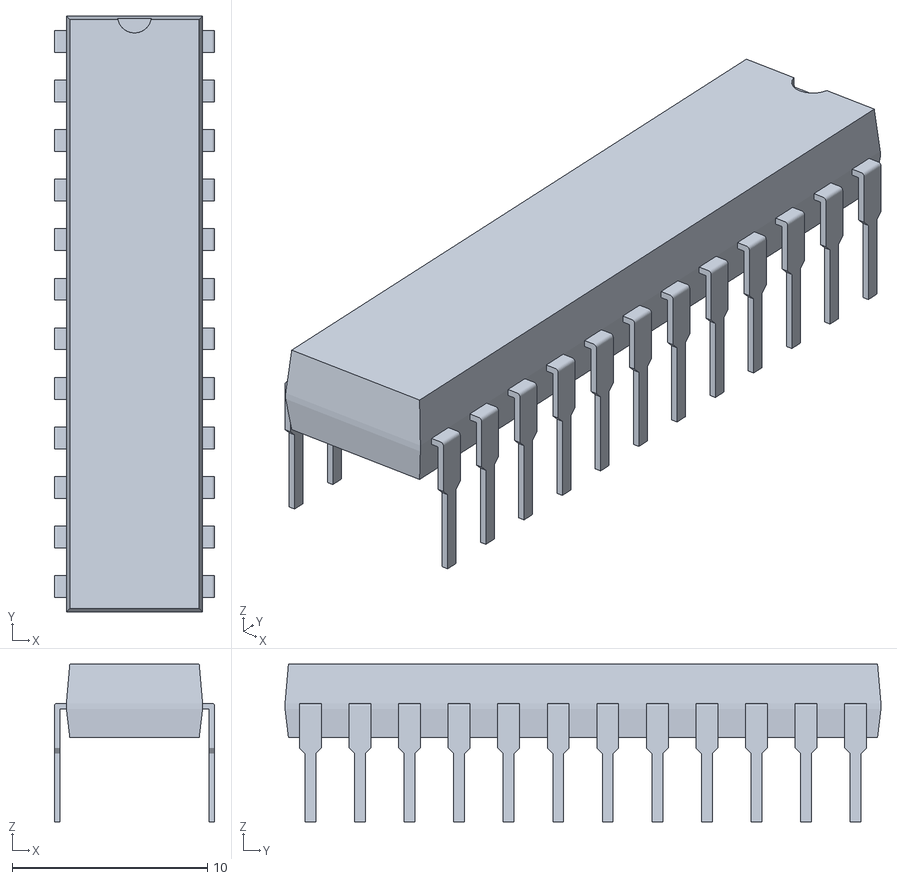
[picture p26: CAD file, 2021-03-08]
KICad_Libraries/MAX7219CNG+/3D/MAX7219CNG+.stl
8.22 x 30.5 x 8.07

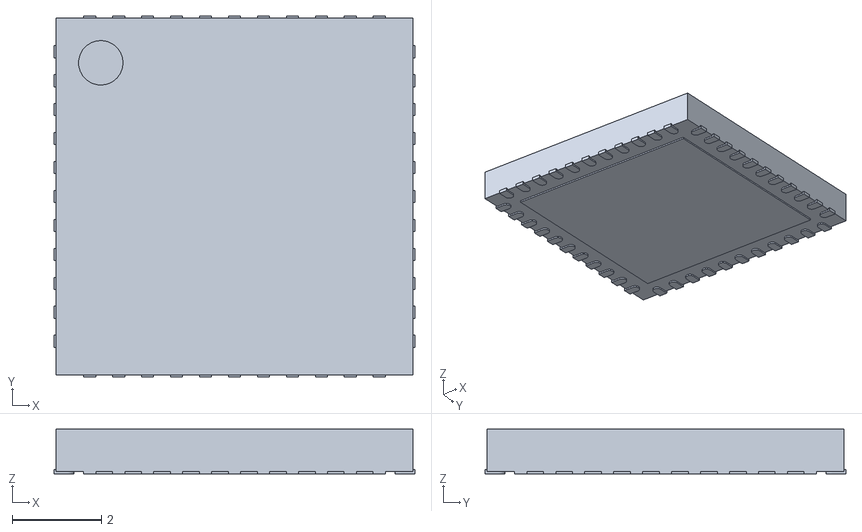
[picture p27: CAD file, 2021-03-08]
KICad_Libraries/MTCH6301-I_ML/3D/MTCH6301-I_ML.stl
8.10 x 8.10 x 1.00

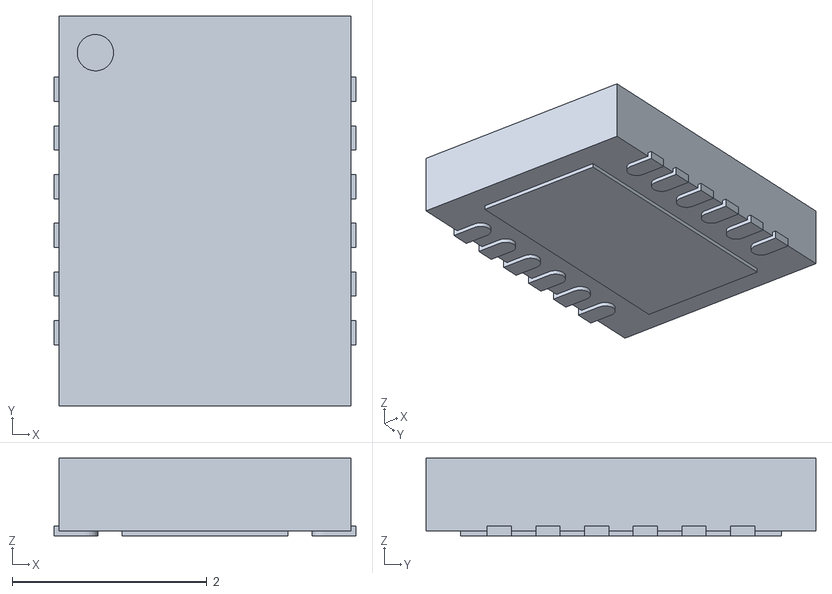
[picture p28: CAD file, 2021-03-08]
KICad_Libraries/LTC3121EDE#PBF.stl
3.10 x 4.00 x 0.8

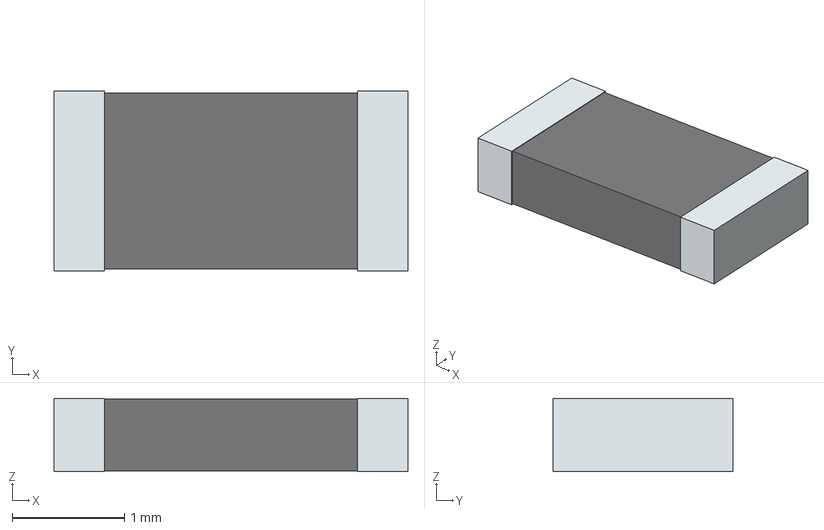
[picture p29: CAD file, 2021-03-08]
KICad_Libraries/RCS12064K70FKEA.stp
3.15 x 1.60 x 0.65 mm
term1
term2

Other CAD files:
KICad_Libraries/MAX7219CNG+/Allegro/dip794w56p254l3054h457q24n.psm
KICad_Libraries/MAX7219CNG+/DEHDL/max7219cng_/chips/chips.prt
KICad_Libraries/MTCH6301-I_ML/DEHDL/mtch6301_i_ml/chips/chips.prt
KICad_Libraries/RCS12064K70FKEA.stl

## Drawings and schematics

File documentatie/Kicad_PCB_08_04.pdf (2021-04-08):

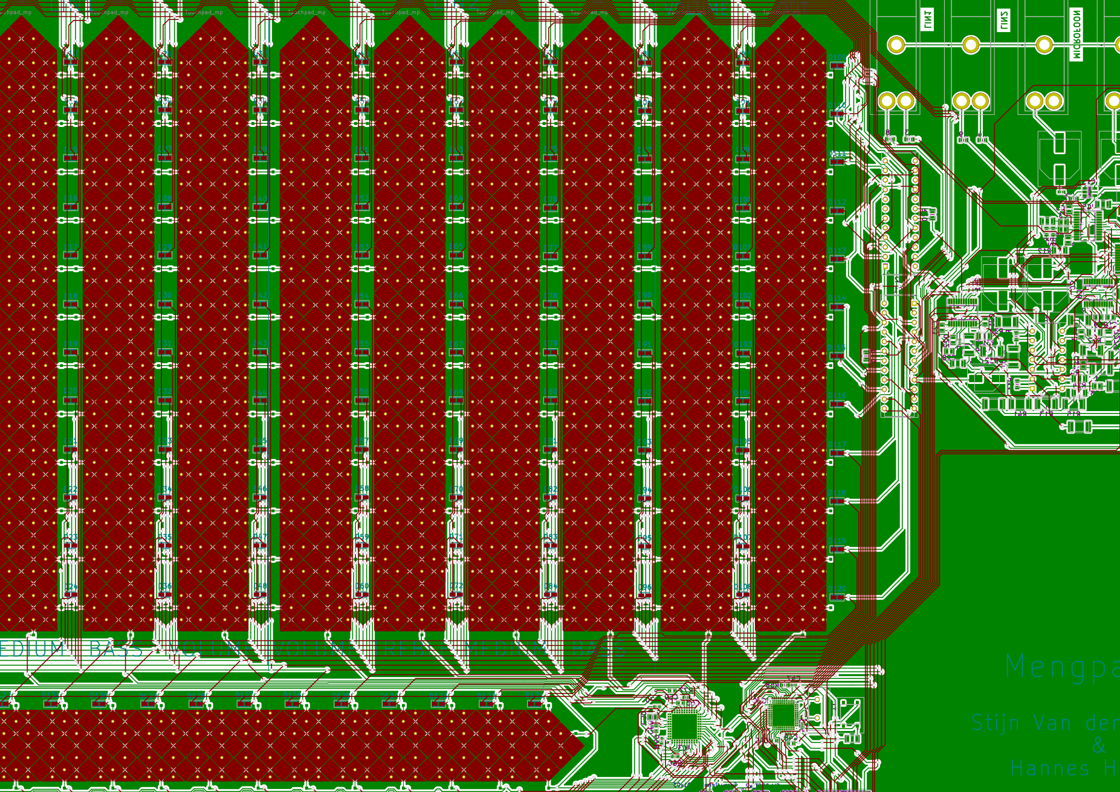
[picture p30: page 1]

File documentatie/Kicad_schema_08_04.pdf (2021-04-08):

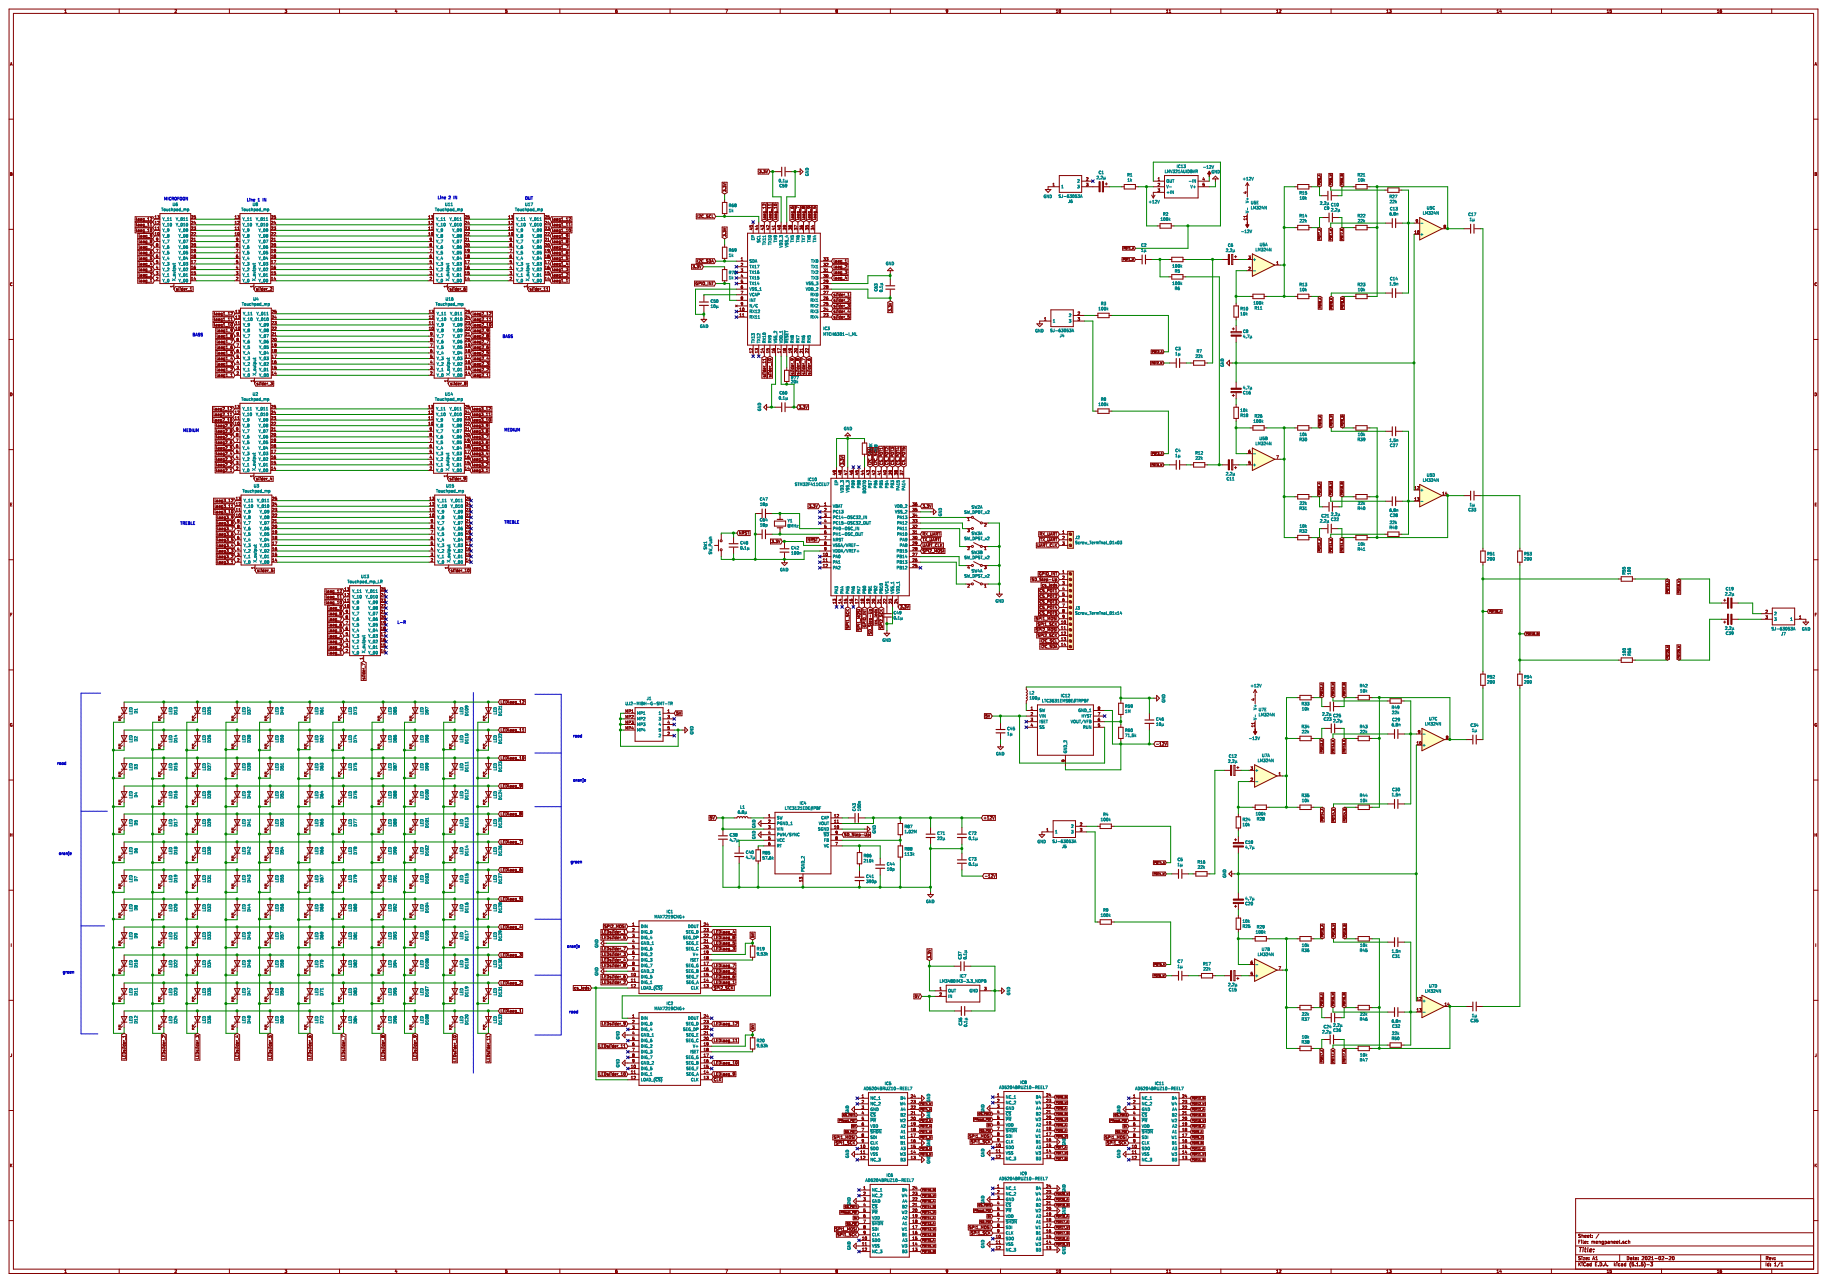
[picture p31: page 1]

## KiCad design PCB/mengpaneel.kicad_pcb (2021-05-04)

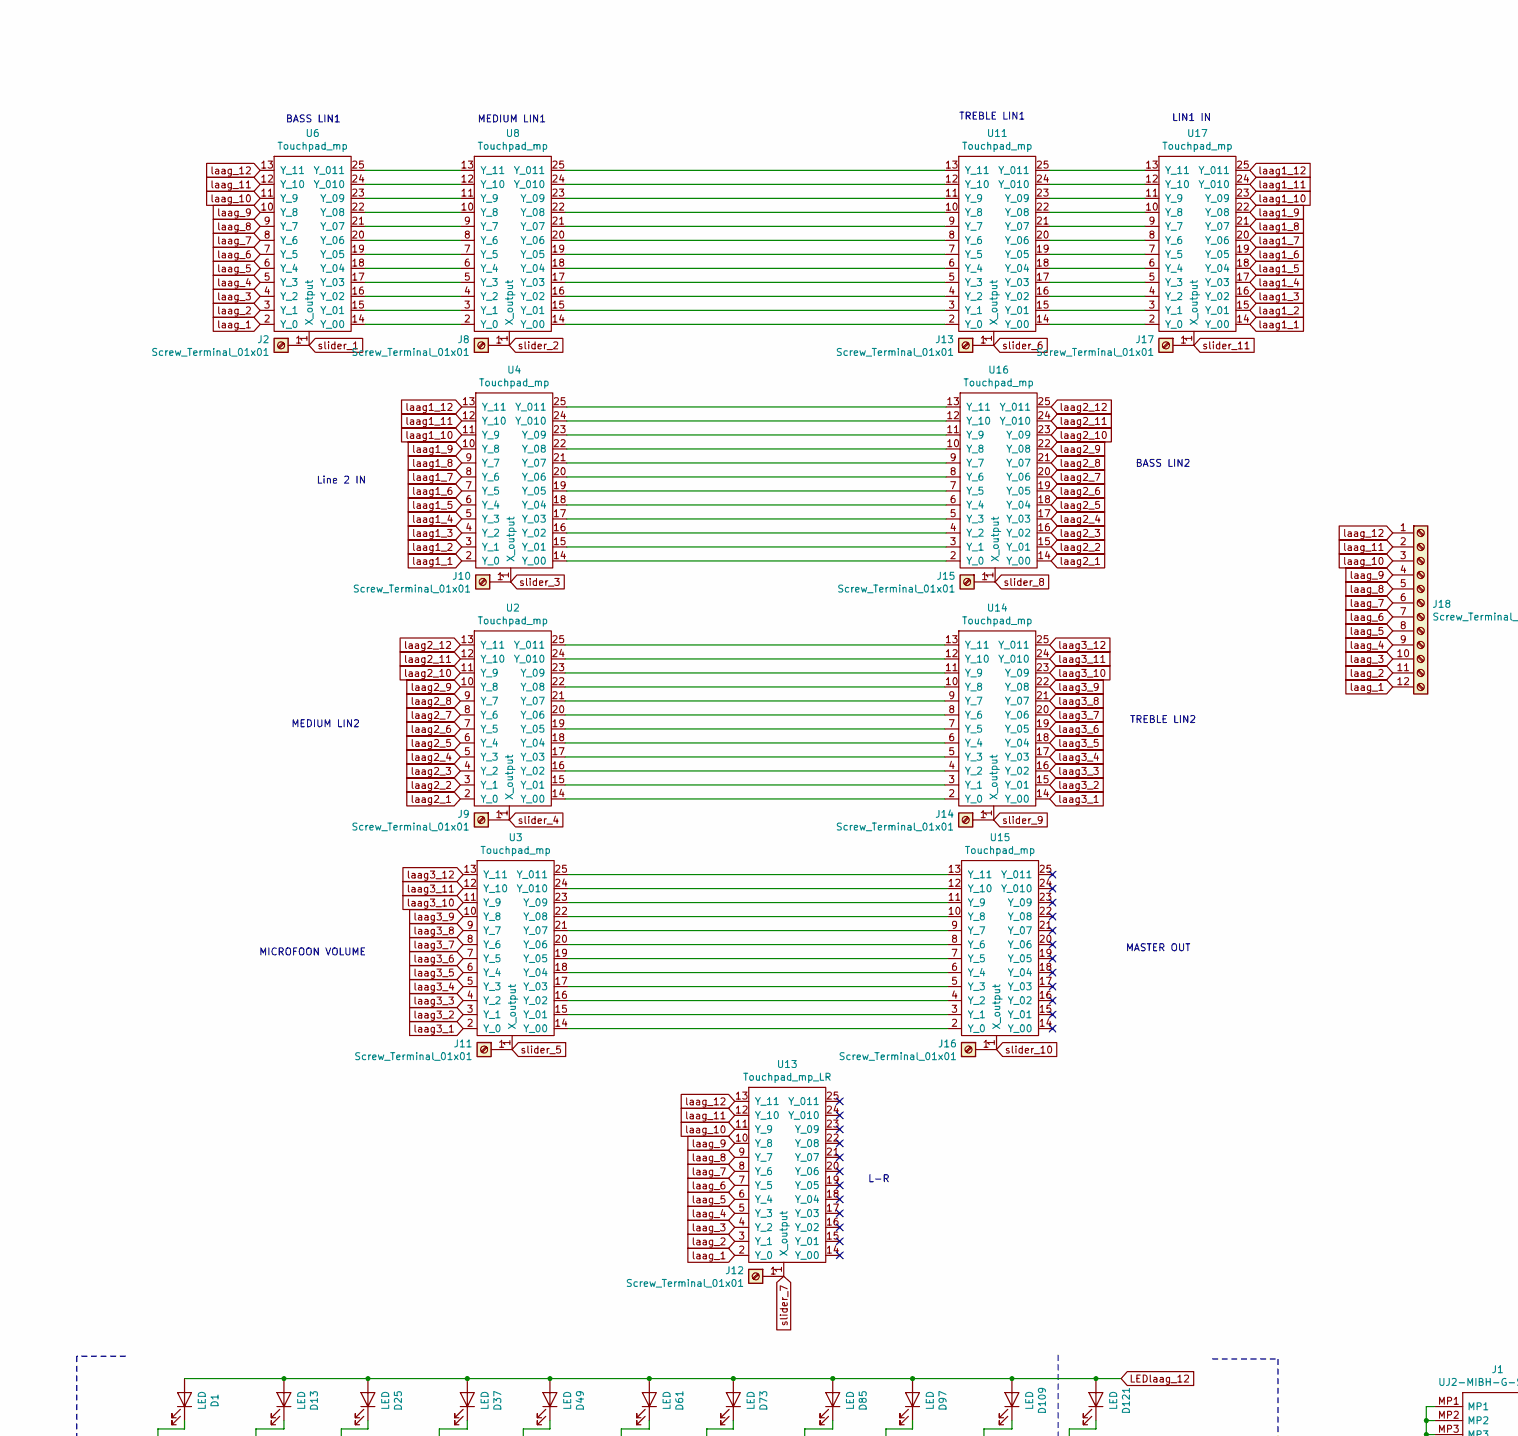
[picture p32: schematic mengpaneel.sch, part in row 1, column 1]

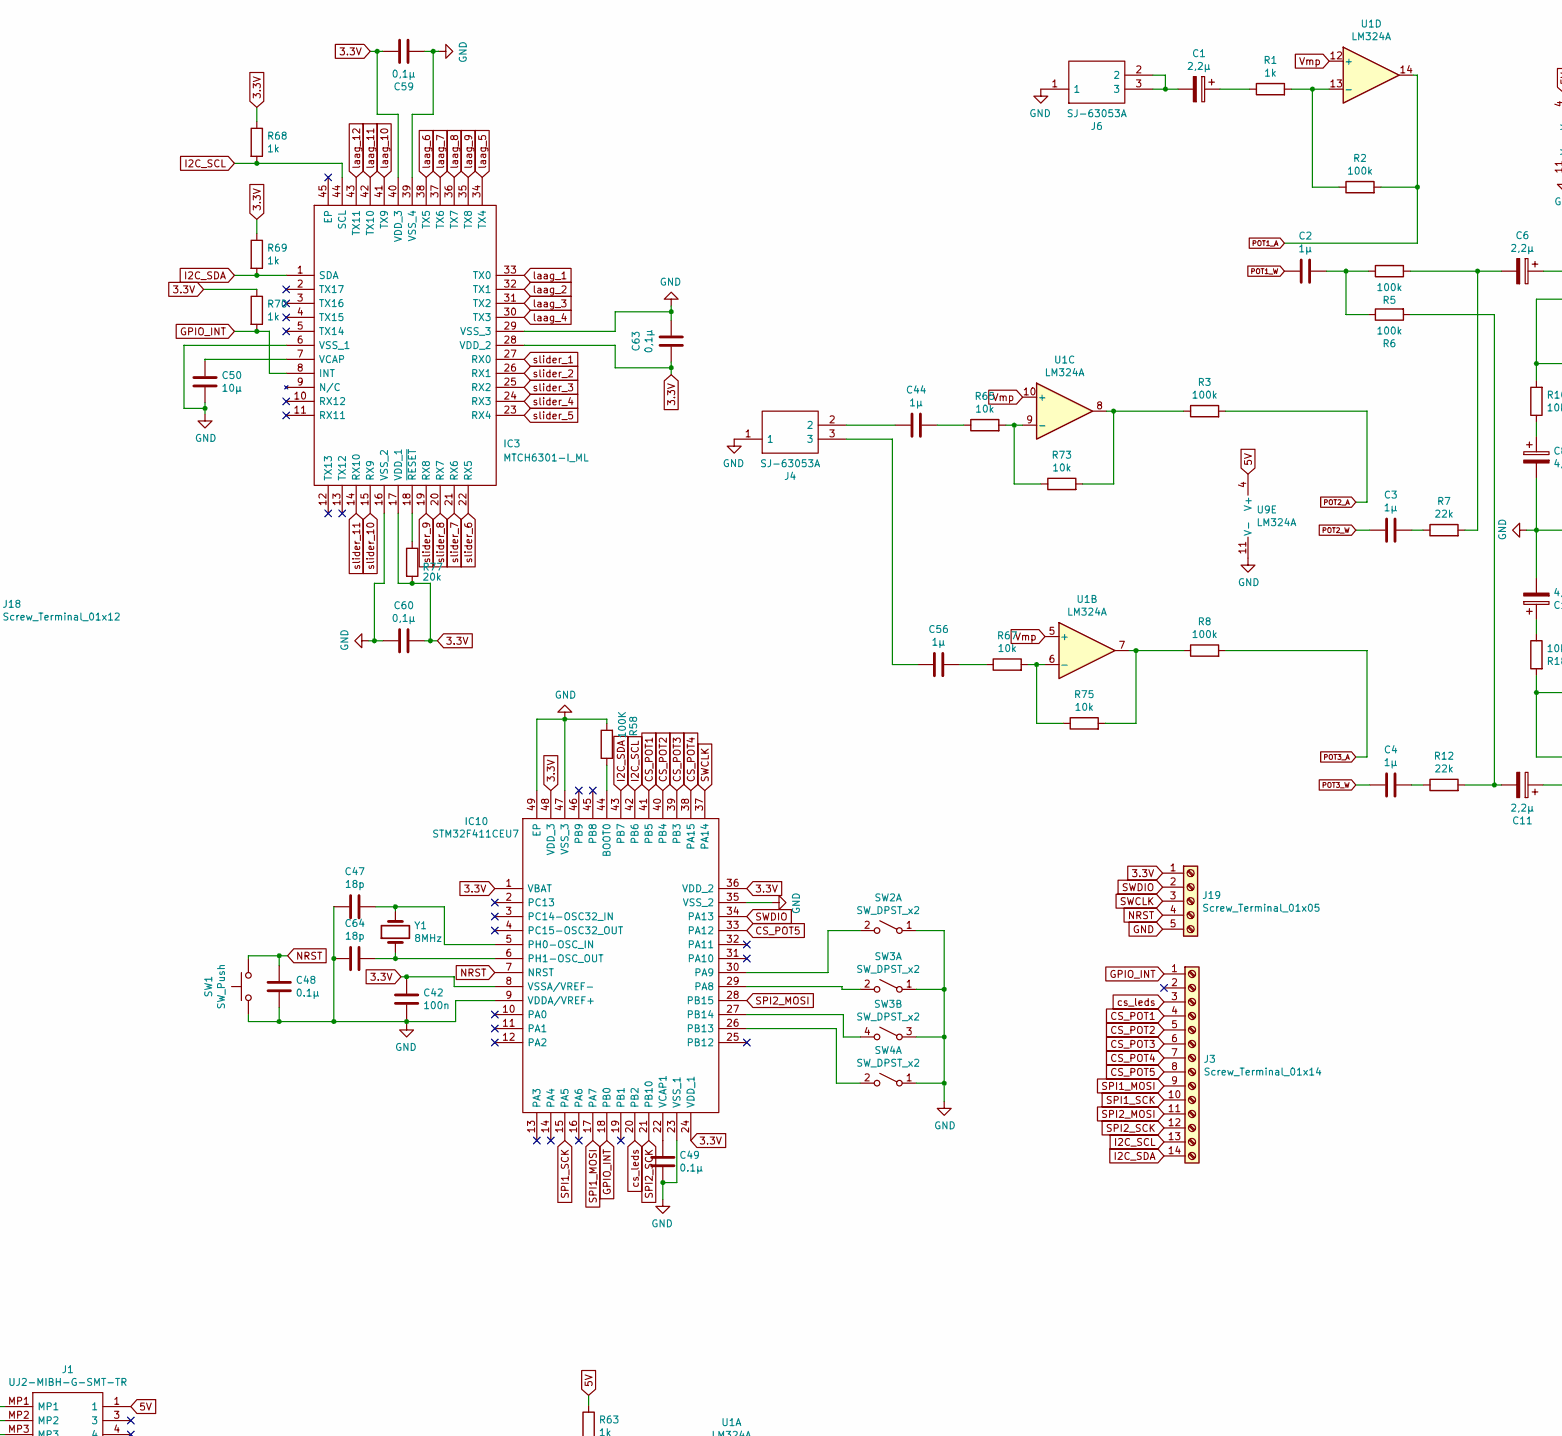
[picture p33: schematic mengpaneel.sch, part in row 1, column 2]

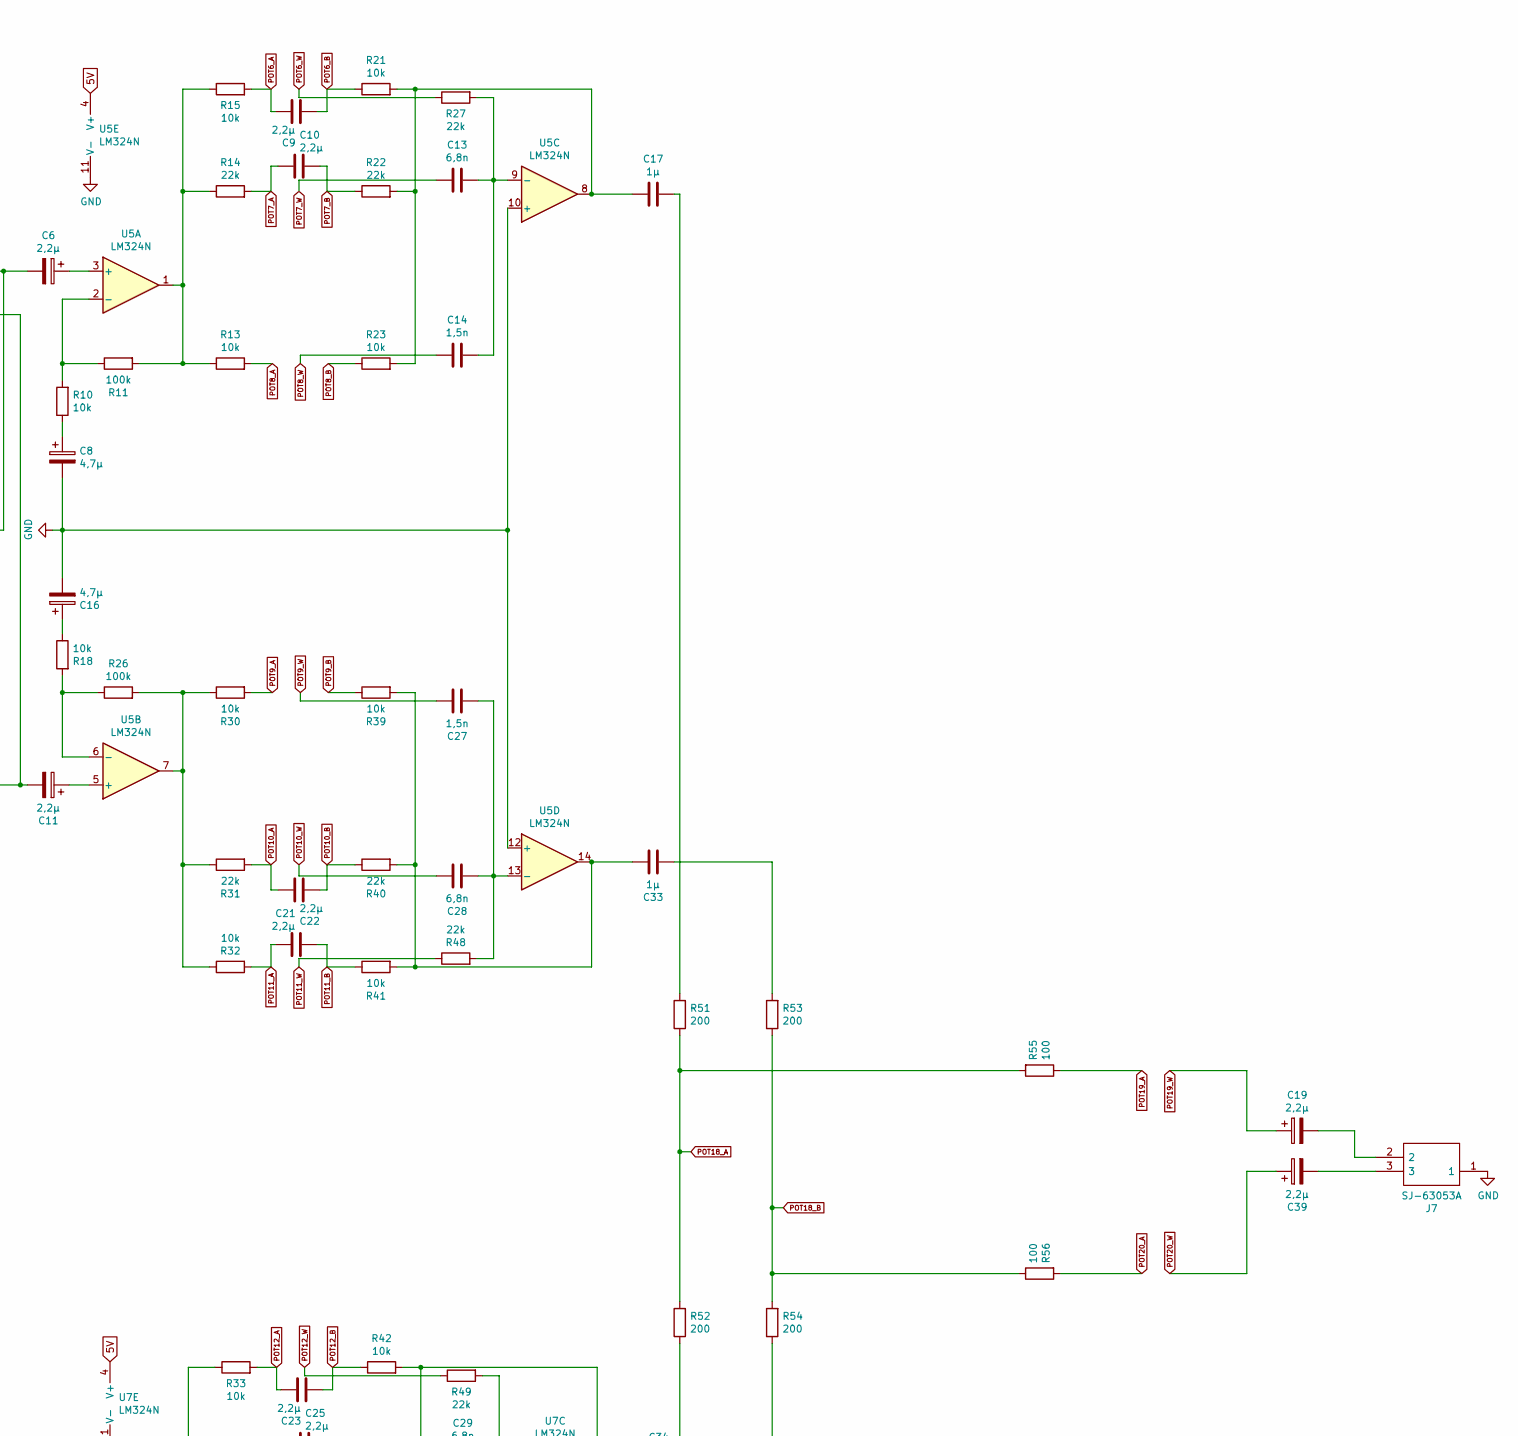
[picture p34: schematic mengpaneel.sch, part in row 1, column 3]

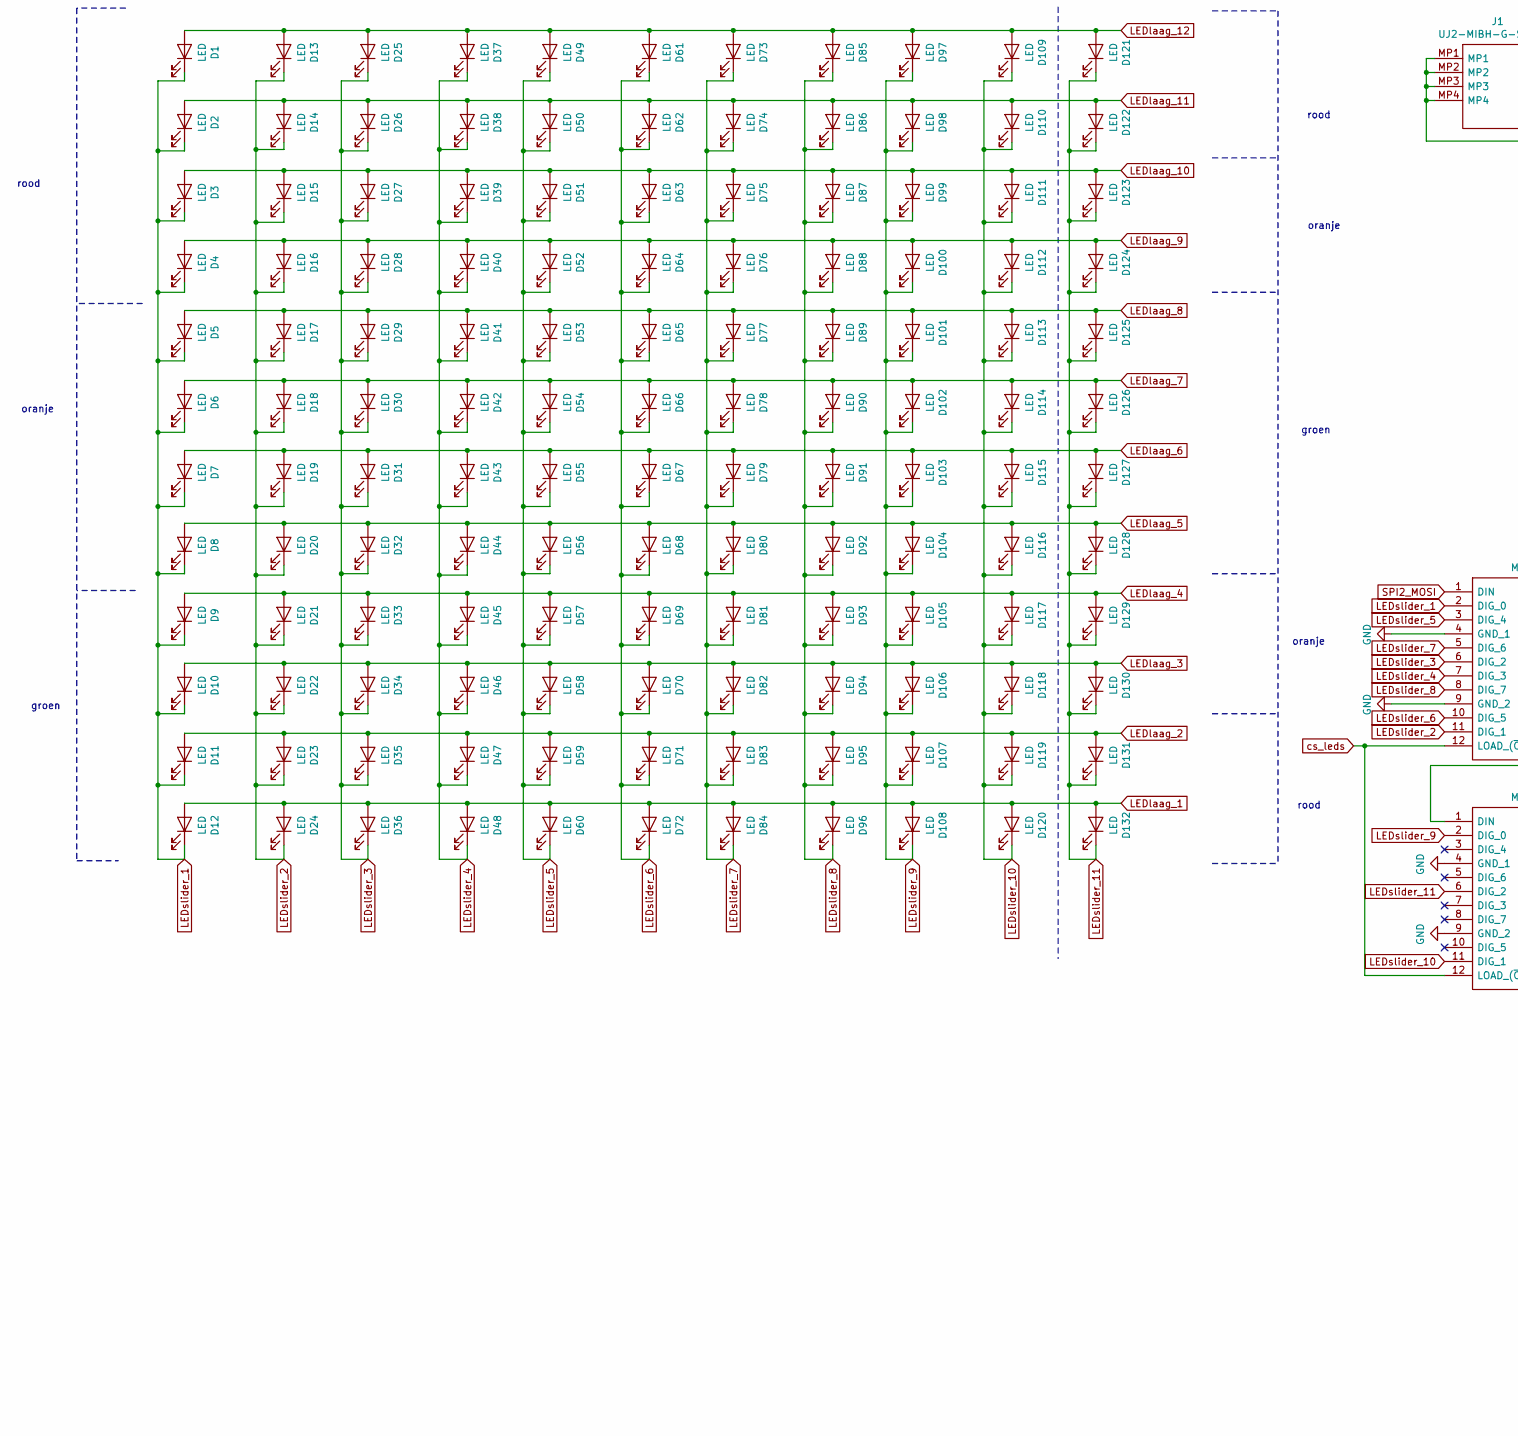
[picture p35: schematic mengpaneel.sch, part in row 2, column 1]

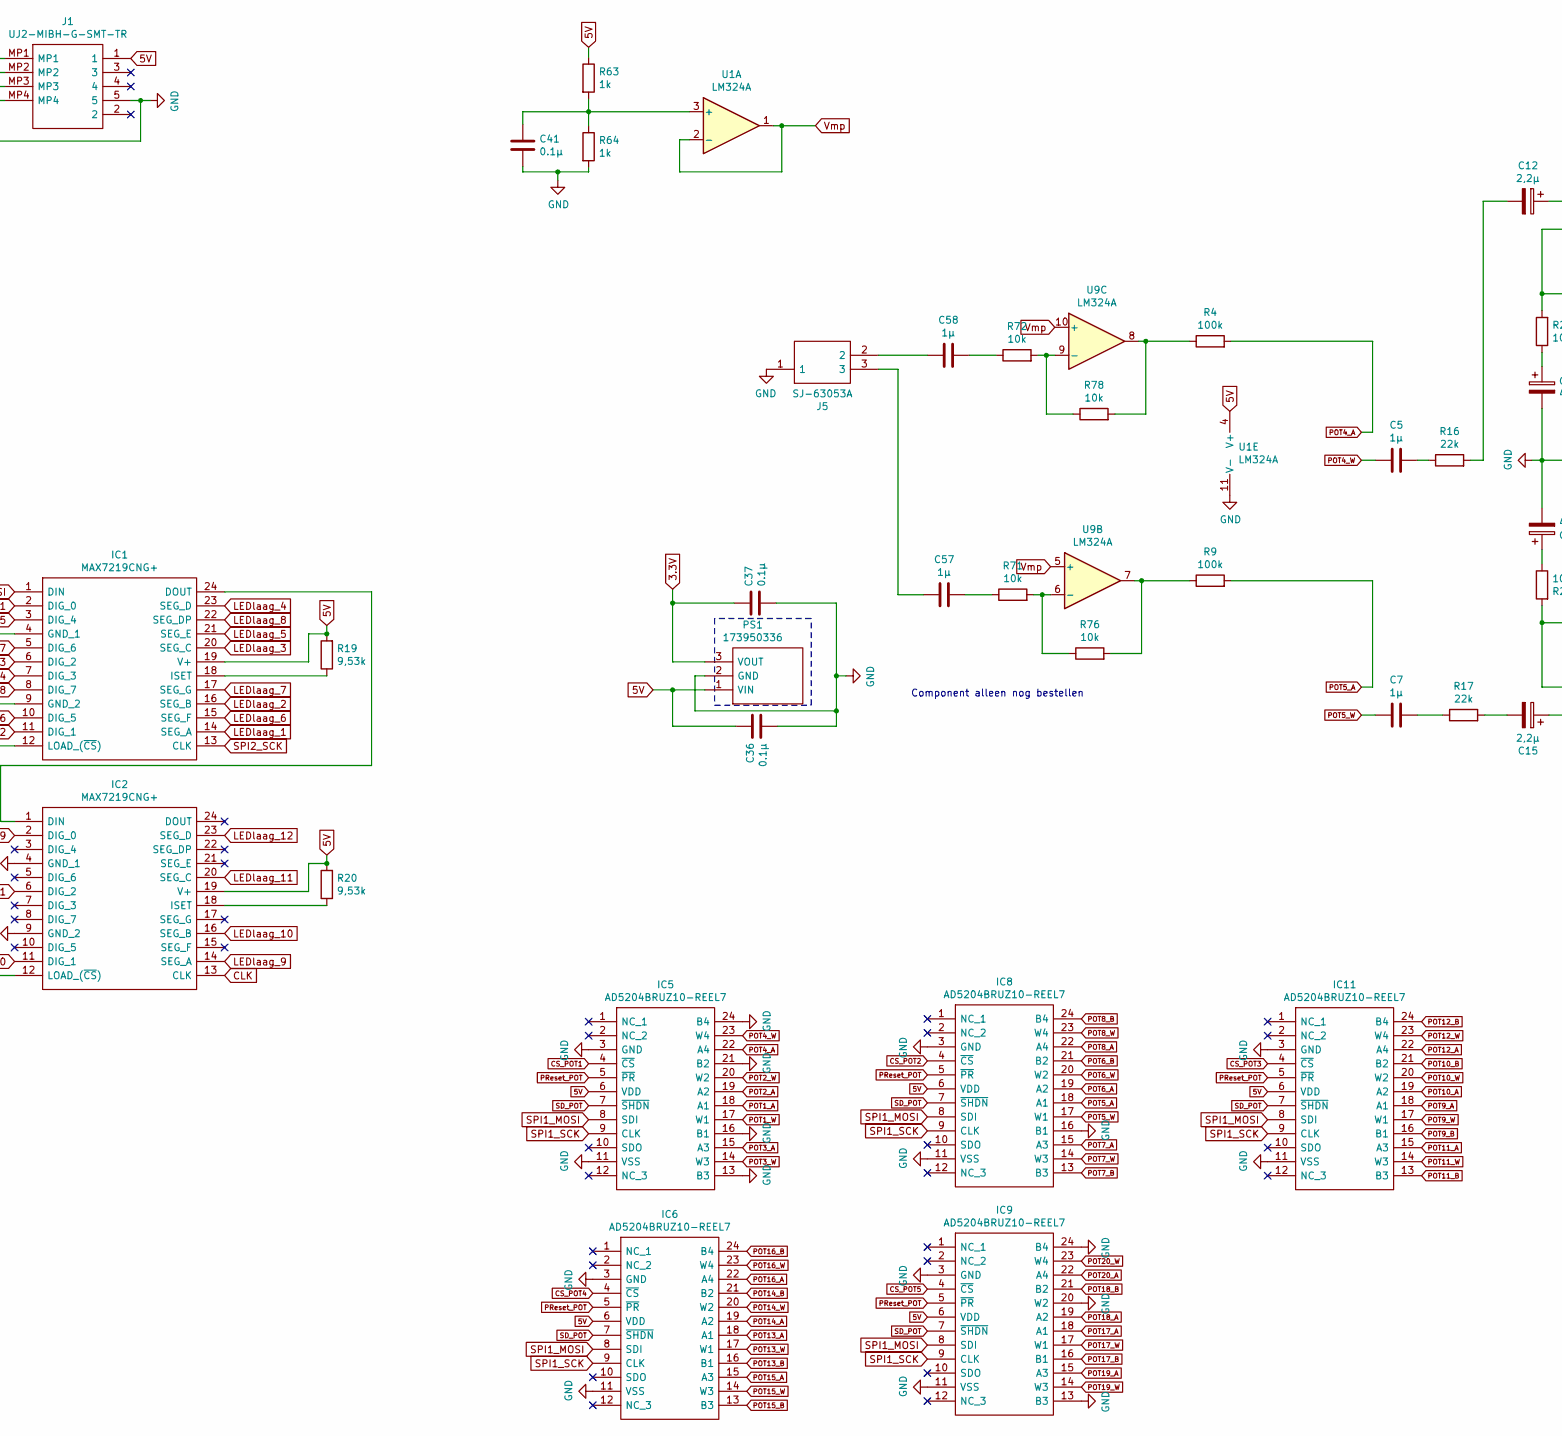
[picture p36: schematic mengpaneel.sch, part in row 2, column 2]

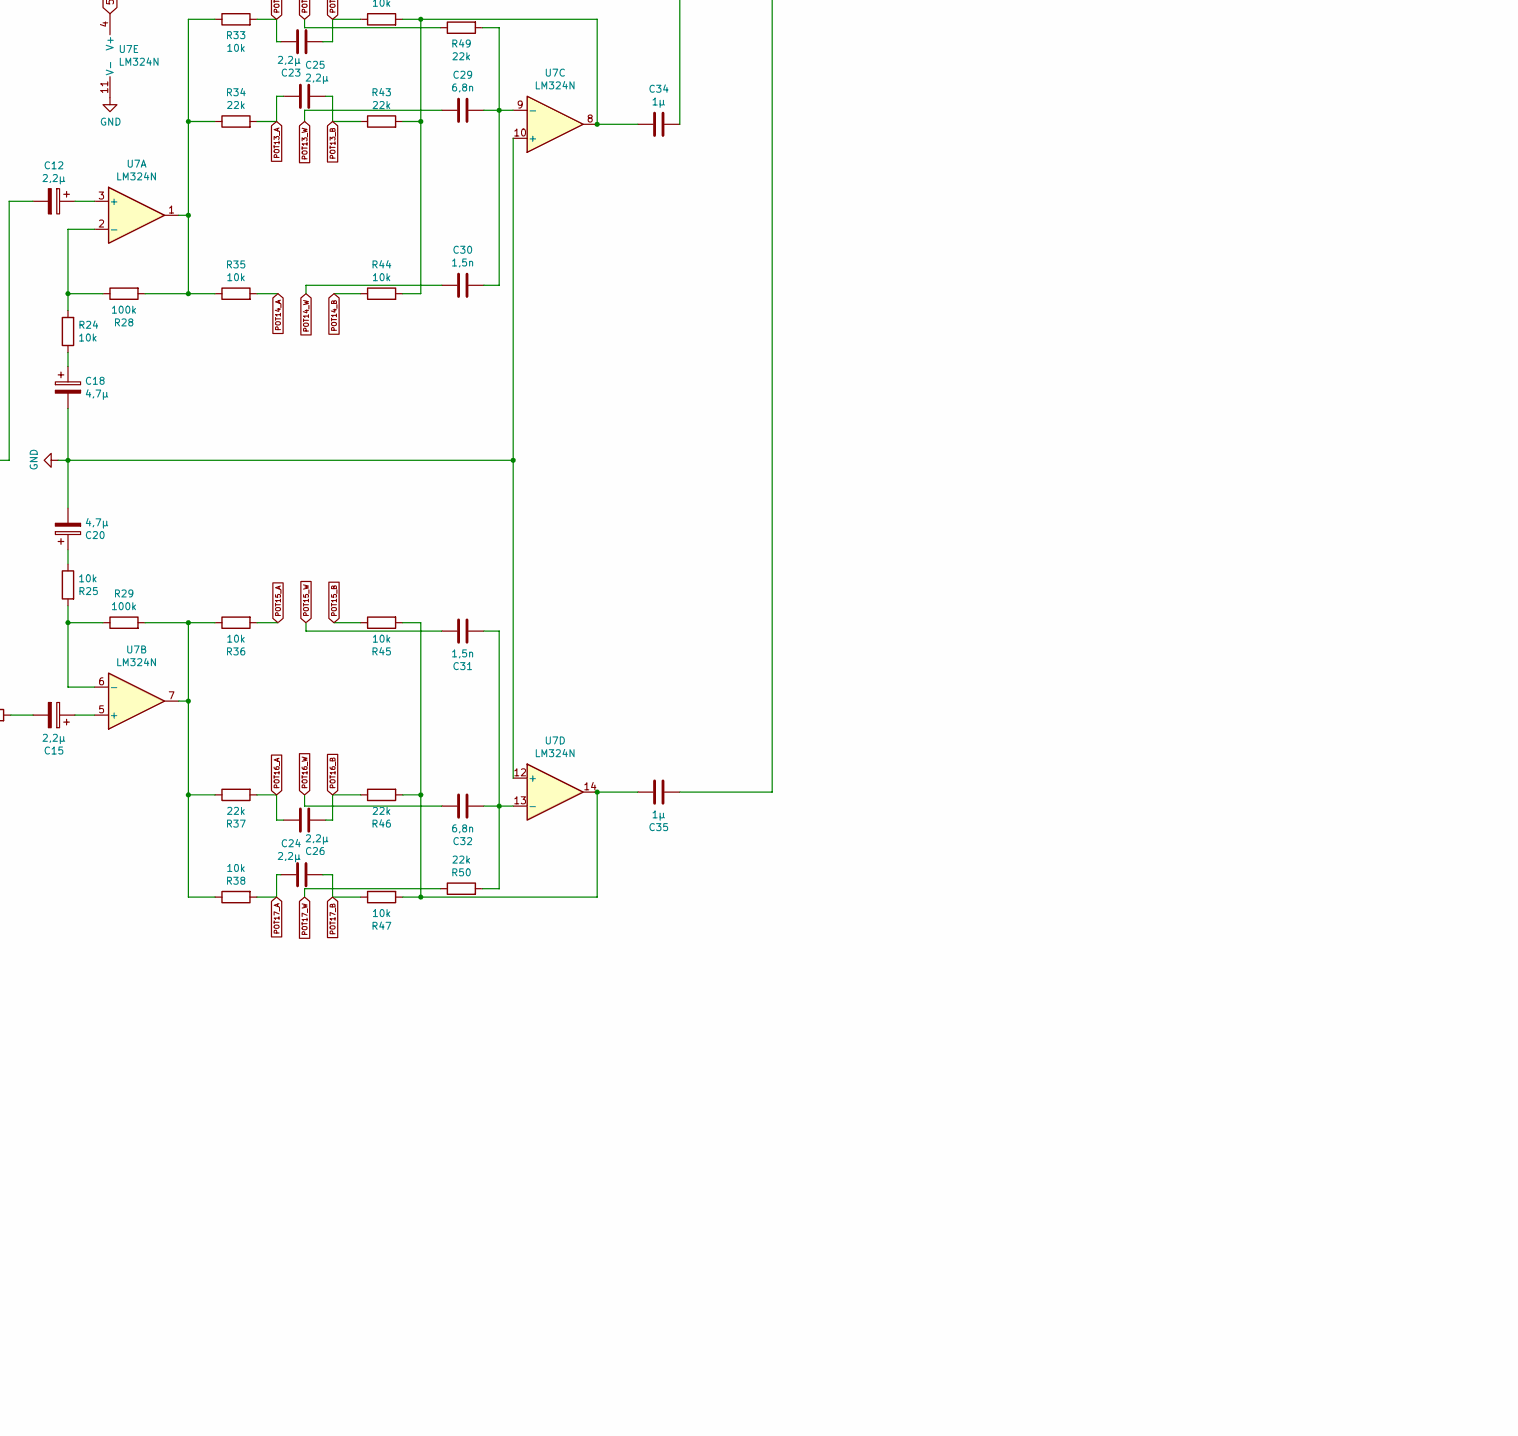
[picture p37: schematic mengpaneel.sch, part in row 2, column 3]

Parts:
C1, C6, C11, C12, C15, C19, C39: 2,2µ; CAPAE1050X1050N
C2, C3, C4, C5, C7, C17, C33, C34, C35, C44, C56, C57, C58: 1µ; CAPC2012X100N
C8, C16, C18, C20: 4,7µ; CAPAE660X610N
C9, C10, C21, C22, C23, C24, C25, C26: 2,2µ; CAPC2012X135N
C13, C28, C29, C32: 6,8n; CAPC2012X100N
C14, C27, C30, C31: 1,5n; CAPC1005X55N
C36, C37, C41, C48, C49: 0.1µ; CAPC1608X90N
C42: 100n; CAPC3216X88N
C47, C64: 18p; CAPC1005X55N
C50: 10µ; CAPC2114X145N
C59, C60, C63: 0,1µ; CAPC1608X90N
D1, D2, D3, D4, D5, D6, D7, D8, D9, D10, D11, D12, D13, D14, D15, D16, D17, D18, D19, D20, D21, D22, D23, D24, D25, D26, D27, D28, D29, D30, D31, D32, D33, D34, D35, D36, D37, D38, D39, D40, D41, D42, D43, D44, D45, D46, D47, D48, D49, D50, D51, D52, D53, D54, D55, D56, D57, D58, D59, D60, D61, D62, D63, D64, D65, D66, D67, D68, D69, D70, D71, D72, D73, D74, D75, D76, D77, D78, D79, D80, D81, D82, D83, D84, D85, D86, D87, D88, D89, D90, D91, D92, D93, D94, D95, D96, D97, D98, D99, D100, D101, D102, D103, D104, D105, D106, D107, D108, D109, D110, D111, D112, D113, D114, D115, D116, D117, D118, D119, D120, D121, D122, D123, D124, D125, D126, D127, D128, D129, D130, D131, D132: LED; LEDM2214X135N
IC1, IC2: MAX7219CNG+; DIP794W56P254L3054H457Q24N; Mouser Part Number 700-MAX7219CNG
IC3: MTCH6301-I_ML; QFN65P800X800X100-45N-D; Mouser Part Number 579-MTCH6301-I/ML
IC5, IC6, IC8, IC9, IC11: AD5204BRUZ10-REEL7; SOP65P640X120-24N; Mouser Part Number 584-AD5204BRUZ10-R7
IC10: STM32F411CEU7; QFN50P700X700X65-49N-D; Mouser Part Number 511-STM32F411CEU7
J1: UJ2-MIBH-G-SMT-TR; UJ2MIBHGSMTTR; Mouser Part Number 490-UJ2-MIBH-G-SMTTR
J2, J8, J9, J10, J11, J12, J13, J14, J15, J16, J17: Screw_Terminal_01x01; PinHeader_1x01_P1.00mm_Vertical
J3: Screw_Terminal_01x14; PinHeader_1x14_P1.00mm_Vertical
J4, J5, J6, J7: SJ-63053A; SJ63053A; Mouser Part Number 490-SJ-63053A
J18: Screw_Terminal_01x12; PinHeader_1x12_P1.00mm_Vertical
J19: Screw_Terminal_01x05; PinHeader_1x05_P1.00mm_Vertical
PS1: 173950336; Mouser Part Number 710-173950336
R1, R63, R64, R68, R69, R70: 1k; RESC1005X40N
R2, R3, R4, R5, R6, R8, R9, R11, R26, R28, R29: 100k; RESC1608X55N
R7, R12, R14, R16, R17, R22, R27, R31, R34, R37, R40, R43, R46, R48, R49, R50: 22k; RESC3216X65N
R10, R13, R15, R18, R21, R23, R24, R25, R30, R32, R33, R35, R36, R38, R39, R41, R42, R44, R45, R47, R65, R67, R71, R72, R73, R75, R76, R78: 10k; RESC5025X70N
R19, R20: 9,53k; RESC2012X60N
R51, R52, R53, R54: 200; RESC5025X70N
R55, R56: 100; RESC5025X70N
R58: 100K; RESC1608X55N
R77: 20k; RESC1005X40N
SW1: SW_Push; PTS526SK15SMTR2LFS
SW2, SW3, SW4: SW_DPST_x2; PinHeader_1x04_P1.00mm_Vertical
U1, U9: LM324A; DIP794W56P254L1905H533Q14N
U2, U3, U4, U6, U8, U11, U14, U15, U16, U17: Touchpad_mp; touchpad_footprint_normaal
U5, U7: LM324N; DIP794W56P254L1905H533Q14N
U13: Touchpad_mp_LR; touchpad_footprint_LR
Y1: 8MHz; ECS80184XCKM

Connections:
3.3V: C37.1, C42.1, C59.1, C60.1, C63.1, IC3.17 (VDD_1), IC3.28 (VDD_2), IC3.40 (VDD_3), IC10.1 (VBAT), IC10.8 (VSSA/VREF-), IC10.24 (VDD_1), IC10.36 (VDD_2), IC10.48 (VDD_3), J19.1, PS1.3 (VOUT), R68.1, R69.1, R70.1, R77.2
5V: C36.1, IC1.19 (V+), IC2.19 (V+), IC5.6 (VDD), IC6.6 (VDD), IC8.6 (VDD), IC9.6 (VDD), IC11.6 (VDD), J1.1, PS1.1 (VIN), R19.2, R20.2, R63.1, U1.4 (V+), U5.4 (V+), U7.4 (V+), U9.4 (V+)
CLK: IC2.13 (CLK)
CS_POT1: IC5.4 (~CS), IC10.41 (PB5), J3.4
CS_POT2: IC8.4 (~CS), IC10.40 (PB4), J3.5
CS_POT3: IC10.39 (PB3), IC11.4 (~CS), J3.6
CS_POT4: IC6.4 (~CS), IC10.38 (PA15), J3.7
CS_POT5: IC9.4 (~CS), IC10.33 (PA12), J3.8
GND: C8.2, C16.2, C18.2, C20.2, C36.2, C37.2, C41.2, C42.2, C47.2, C48.2, C49.2, C50.2, C59.2, C60.2, C63.2, C64.1, IC1.4 (GND_1), IC1.9 (GND_2), IC2.4 (GND_1), IC2.9 (GND_2), IC3.6 (VSS_1), IC3.16 (VSS_2), IC3.29 (VSS_3), IC3.39 (VSS_4), IC5.3 (GND), IC5.11 (VSS), IC5.13 (B3), IC5.16 (B1), IC5.21 (B2), IC5.24 (B4), IC6.3 (GND), IC6.11 (VSS), IC8.3 (GND), IC8.11 (VSS), IC8.16 (B1), IC9.3 (GND), IC9.11 (VSS), IC9.13 (B3), IC9.20 (W2), IC9.24 (B4), IC10.9 (VDDA/VREF+), IC10.23 (VSS_1), IC10.35 (VSS_2), IC10.47 (VSS_3), IC10.49 (EP), IC11.3 (GND), IC11.11 (VSS), J1.5, J1.MP1, J1.MP2, J1.MP3, J1.MP4, J4.1, J5.1, J6.1, J7.1, J19.5, PS1.2 (GND), R58.2, R64.2, SW1.1, SW2.1 (A), SW3.1 (A), SW3.3 (A), SW4.1 (A), U1.11 (V-), U5.10 (+), U5.11 (V-), U5.12 (+), U7.10 (+), U7.11 (V-), U7.12 (+), U9.11 (V-)
GPIO_INT: IC3.8 (INT), IC10.18 (PB0), J3.1, R70.2
I2C_SCL: IC3.44 (SCL), IC10.42 (PB6), J3.13, R68.2
I2C_SDA: IC3.1 (SDA), IC10.43 (PB7), J3.14, R69.2
LEDlaag_1: D12.2 (A), D24.2 (A), D36.2 (A), D48.2 (A), D60.2 (A), D72.2 (A), D84.2 (A), D96.2 (A), D108.2 (A), D120.2 (A), D132.2 (A), IC1.14 (SEG_A)
LEDlaag_2: D11.2 (A), D23.2 (A), D35.2 (A), D47.2 (A), D59.2 (A), D71.2 (A), D83.2 (A), D95.2 (A), D107.2 (A), D119.2 (A), D131.2 (A), IC1.16 (SEG_B)
LEDlaag_3: D10.2 (A), D22.2 (A), D34.2 (A), D46.2 (A), D58.2 (A), D70.2 (A), D82.2 (A), D94.2 (A), D106.2 (A), D118.2 (A), D130.2 (A), IC1.20 (SEG_C)
LEDlaag_4: D9.2 (A), D21.2 (A), D33.2 (A), D45.2 (A), D57.2 (A), D69.2 (A), D81.2 (A), D93.2 (A), D105.2 (A), D117.2 (A), D129.2 (A), IC1.23 (SEG_D)
LEDlaag_5: D8.2 (A), D20.2 (A), D32.2 (A), D44.2 (A), D56.2 (A), D68.2 (A), D80.2 (A), D92.2 (A), D104.2 (A), D116.2 (A), D128.2 (A), IC1.21 (SEG_E)
LEDlaag_6: D7.2 (A), D19.2 (A), D31.2 (A), D43.2 (A), D55.2 (A), D67.2 (A), D79.2 (A), D91.2 (A), D103.2 (A), D115.2 (A), D127.2 (A), IC1.15 (SEG_F)
LEDlaag_7: D6.2 (A), D18.2 (A), D30.2 (A), D42.2 (A), D54.2 (A), D66.2 (A), D78.2 (A), D90.2 (A), D102.2 (A), D114.2 (A), D126.2 (A), IC1.17 (SEG_G)
LEDlaag_8: D5.2 (A), D17.2 (A), D29.2 (A), D41.2 (A), D53.2 (A), D65.2 (A), D77.2 (A), D89.2 (A), D101.2 (A), D113.2 (A), D125.2 (A), IC1.22 (SEG_DP)
LEDlaag_9: D4.2 (A), D16.2 (A), D28.2 (A), D40.2 (A), D52.2 (A), D64.2 (A), D76.2 (A), D88.2 (A), D100.2 (A), D112.2 (A), D124.2 (A), IC2.14 (SEG_A)
LEDlaag_10: D3.2 (A), D15.2 (A), D27.2 (A), D39.2 (A), D51.2 (A), D63.2 (A), D75.2 (A), D87.2 (A), D99.2 (A), D111.2 (A), D123.2 (A), IC2.16 (SEG_B)
LEDlaag_11: D2.2 (A), D14.2 (A), D26.2 (A), D38.2 (A), D50.2 (A), D62.2 (A), D74.2 (A), D86.2 (A), D98.2 (A), D110.2 (A), D122.2 (A), IC2.20 (SEG_C)
LEDlaag_12: D1.2 (A), D13.2 (A), D25.2 (A), D37.2 (A), D49.2 (A), D61.2 (A), D73.2 (A), D85.2 (A), D97.2 (A), D109.2 (A), D121.2 (A), IC2.23 (SEG_D)
LEDslider_1: D1.1 (K), D2.1 (K), D3.1 (K), D4.1 (K), D5.1 (K), D6.1 (K), D7.1 (K), D8.1 (K), D9.1 (K), D10.1 (K), D11.1 (K), D12.1 (K), IC1.2 (DIG_0)
LEDslider_2: D13.1 (K), D14.1 (K), D15.1 (K), D16.1 (K), D17.1 (K), D18.1 (K), D19.1 (K), D20.1 (K), D21.1 (K), D22.1 (K), D23.1 (K), D24.1 (K), IC1.11 (DIG_1)
LEDslider_3: D25.1 (K), D26.1 (K), D27.1 (K), D28.1 (K), D29.1 (K), D30.1 (K), D31.1 (K), D32.1 (K), D33.1 (K), D34.1 (K), D35.1 (K), D36.1 (K), IC1.6 (DIG_2)
LEDslider_4: D37.1 (K), D38.1 (K), D39.1 (K), D40.1 (K), D41.1 (K), D42.1 (K), D43.1 (K), D44.1 (K), D45.1 (K), D46.1 (K), D47.1 (K), D48.1 (K), IC1.7 (DIG_3)
LEDslider_5: D49.1 (K), D50.1 (K), D51.1 (K), D52.1 (K), D53.1 (K), D54.1 (K), D55.1 (K), D56.1 (K), D57.1 (K), D58.1 (K), D59.1 (K), D60.1 (K), IC1.3 (DIG_4)
LEDslider_6: D61.1 (K), D62.1 (K), D63.1 (K), D64.1 (K), D65.1 (K), D66.1 (K), D67.1 (K), D68.1 (K), D69.1 (K), D70.1 (K), D71.1 (K), D72.1 (K), IC1.10 (DIG_5)
LEDslider_7: D73.1 (K), D74.1 (K), D75.1 (K), D76.1 (K), D77.1 (K), D78.1 (K), D79.1 (K), D80.1 (K), D81.1 (K), D82.1 (K), D83.1 (K), D84.1 (K), IC1.5 (DIG_6)
LEDslider_8: D85.1 (K), D86.1 (K), D87.1 (K), D88.1 (K), D89.1 (K), D90.1 (K), D91.1 (K), D92.1 (K), D93.1 (K), D94.1 (K), D95.1 (K), D96.1 (K), IC1.8 (DIG_7)
LEDslider_9: D97.1 (K), D98.1 (K), D99.1 (K), D100.1 (K), D101.1 (K), D102.1 (K), D103.1 (K), D104.1 (K), D105.1 (K), D106.1 (K), D107.1 (K), D108.1 (K), IC2.2 (DIG_0)
LEDslider_10: D109.1 (K), D110.1 (K), D111.1 (K), D112.1 (K), D113.1 (K), D114.1 (K), D115.1 (K), D116.1 (K), D117.1 (K), D118.1 (K), D119.1 (K), D120.1 (K), IC2.11 (DIG_1)
LEDslider_11: D121.1 (K), D122.1 (K), D123.1 (K), D124.1 (K), D125.1 (K), D126.1 (K), D127.1 (K), D128.1 (K), D129.1 (K), D130.1 (K), D131.1 (K), D132.1 (K), IC2.6 (DIG_2)
NRST: C48.1, IC10.7 (NRST), J19.4, SW1.2
unnamed: C1.1, R1.1
unnamed: C1.2, J6.2, J6.3
unnamed: C2.2, R5.1, R6.1
unnamed: C3.2, R7.1
unnamed: C4.2, R12.1
unnamed: C5.2, R16.1
unnamed: C6.1, U5.3 (+)
unnamed: C6.2, R5.2, R7.2
unnamed: C7.2, R17.1
unnamed: C8.1, R10.1
unnamed: C11.1, U5.5 (+)
unnamed: C11.2, R6.2, R12.2
unnamed: C12.1, U7.3 (+)
unnamed: C12.2, R16.2
unnamed: C13.2, C14.2, R27.2, U5.9 (-)
unnamed: C15.1, U7.5 (+)
unnamed: C15.2, R17.2
unnamed: C16.1, R18.1
unnamed: C17.1, R21.2, R22.2, R23.2, U5.8
unnamed: C17.2, R51.2
unnamed: C18.1, R24.1
unnamed: C19.2, J7.2
unnamed: C20.1, R25.1
unnamed: C27.2, C28.2, R48.2, U5.13 (-)
unnamed: C29.2, C30.2, R49.2, U7.9 (-)
unnamed: C31.2, C32.2, R50.2, U7.13 (-)
unnamed: C33.1, R39.2, R40.2, R41.2, U5.14
unnamed: C33.2, R53.2
unnamed: C34.1, R42.2, R43.2, R44.2, U7.8
unnamed: C34.2, R52.1
unnamed: C35.1, R45.2, R46.2, R47.2, U7.14
unnamed: C35.2, R54.1
unnamed: C39.2, J7.3
unnamed: C41.1, R63.2, R64.1, U1.3 (+)
unnamed: C44.1, J4.2
unnamed: C44.2, R65.1
unnamed: C47.1, IC10.5 (PH0-OSC_IN), Y1.2
unnamed: C49.1, IC10.22 (VCAP1)
unnamed: C50.1, IC3.7 (VCAP)
unnamed: C56.1, J4.3
unnamed: C56.2, R67.1
unnamed: C57.1, J5.3
unnamed: C57.2, R71.1
unnamed: C58.1, J5.2
unnamed: C58.2, R72.1
unnamed: C64.2, IC10.6 (PH1-OSC_OUT), Y1.1
unnamed: IC1.18 (ISET), R19.1
unnamed: IC1.24 (DOUT), IC2.1 (DIN)
unnamed: IC2.18 (ISET), R20.1
unnamed: IC3.18 (~RESET), R77.1
unnamed: IC10.26 (PB13), SW4.2 (B)
unnamed: IC10.27 (PB14), SW3.4 (B)
unnamed: IC10.29 (PA8), SW3.2 (B)
unnamed: IC10.30 (PA9), SW2.2 (B)
unnamed: IC10.44 (BOOT0), R58.1
unnamed: R1.2, R2.1, U1.13 (-)
unnamed: R3.1, R73.2, U1.8
unnamed: R4.1, R78.2, U9.8
unnamed: R10.2, R11.1, U5.2 (-)
unnamed: R11.2, R13.1, R14.1, R15.1, U5.1
unnamed: R18.2, R26.1, U5.6 (-)
unnamed: R24.2, R28.1, U7.2 (-)
unnamed: R25.2, R29.1, U7.6 (-)
unnamed: R26.2, R30.1, R31.1, R32.1, U5.7
unnamed: R28.2, R33.1, R34.1, R35.1, U7.1
unnamed: R29.2, R36.1, R37.1, R38.1, U7.7
unnamed: R65.2, R73.1, U1.9 (-)
unnamed: R67.2, R75.1, U1.6 (-)
unnamed: R71.2, R76.1, U9.6 (-)
unnamed: R72.2, R78.1, U9.9 (-)
unnamed: R8.1, R75.2, U1.7
unnamed: R9.1, R76.2, U9.7
unnamed: U6.14 (Y_00), U8.2 (Y_0)
unnamed: U6.15 (Y_01), U8.3 (Y_1)
unnamed: U6.16 (Y_02), U8.4 (Y_2)
unnamed: U6.17 (Y_03), U8.5 (Y_3)
unnamed: U6.18 (Y_04), U8.6 (Y_4)
unnamed: U6.19 (Y_05), U8.7 (Y_5)
unnamed: U6.20 (Y_06), U8.8 (Y_6)
unnamed: U6.21 (Y_07), U8.9 (Y_7)
unnamed: U6.22 (Y_08), U8.10 (Y_8)
unnamed: U6.23 (Y_09), U8.11 (Y_9)
unnamed: U6.24 (Y_010), U8.12 (Y_10)
unnamed: U6.25 (Y_011), U8.13 (Y_11)
unnamed: U8.14 (Y_00), U11.2 (Y_0)
unnamed: U8.15 (Y_01), U11.3 (Y_1)
unnamed: U8.16 (Y_02), U11.4 (Y_2)
unnamed: U8.17 (Y_03), U11.5 (Y_3)
unnamed: U8.18 (Y_04), U11.6 (Y_4)
unnamed: U8.19 (Y_05), U11.7 (Y_5)
unnamed: U8.20 (Y_06), U11.8 (Y_6)
unnamed: U8.21 (Y_07), U11.9 (Y_7)
unnamed: U8.22 (Y_08), U11.10 (Y_8)
unnamed: U8.23 (Y_09), U11.11 (Y_9)
unnamed: U8.24 (Y_010), U11.12 (Y_10)
unnamed: U8.25 (Y_011), U11.13 (Y_11)
unnamed: U11.14 (Y_00), U17.2 (Y_0)
unnamed: U11.15 (Y_01), U17.3 (Y_1)
unnamed: U11.16 (Y_02), U17.4 (Y_2)
unnamed: U11.17 (Y_03), U17.5 (Y_3)
unnamed: U11.18 (Y_04), U17.6 (Y_4)
unnamed: U11.19 (Y_05), U17.7 (Y_5)
unnamed: U11.20 (Y_06), U17.8 (Y_6)
unnamed: U11.21 (Y_07), U17.9 (Y_7)
unnamed: U11.22 (Y_08), U17.10 (Y_8)
unnamed: U11.23 (Y_09), U17.11 (Y_9)
unnamed: U11.24 (Y_010), U17.12 (Y_10)
unnamed: U11.25 (Y_011), U17.13 (Y_11)
unnamed: U2.14 (Y_00), U14.2 (Y_0)
unnamed: U2.15 (Y_01), U14.3 (Y_1)
unnamed: U2.16 (Y_02), U14.4 (Y_2)
unnamed: U2.17 (Y_03), U14.5 (Y_3)
unnamed: U2.18 (Y_04), U14.6 (Y_4)
unnamed: U2.19 (Y_05), U14.7 (Y_5)
unnamed: U2.20 (Y_06), U14.8 (Y_6)
unnamed: U2.21 (Y_07), U14.9 (Y_7)
unnamed: U2.22 (Y_08), U14.10 (Y_8)
unnamed: U2.23 (Y_09), U14.11 (Y_9)
unnamed: U2.24 (Y_010), U14.12 (Y_10)
unnamed: U2.25 (Y_011), U14.13 (Y_11)
unnamed: U3.14 (Y_00), U15.2 (Y_0)
unnamed: U3.15 (Y_01), U15.3 (Y_1)
unnamed: U3.16 (Y_02), U15.4 (Y_2)
unnamed: U3.17 (Y_03), U15.5 (Y_3)
unnamed: U3.18 (Y_04), U15.6 (Y_4)
unnamed: U3.19 (Y_05), U15.7 (Y_5)
unnamed: U3.20 (Y_06), U15.8 (Y_6)
unnamed: U3.21 (Y_07), U15.9 (Y_7)
unnamed: U3.22 (Y_08), U15.10 (Y_8)
unnamed: U3.23 (Y_09), U15.11 (Y_9)
unnamed: U3.24 (Y_010), U15.12 (Y_10)
unnamed: U3.25 (Y_011), U15.13 (Y_11)
unnamed: U4.14 (Y_00), U16.2 (Y_0)
unnamed: U4.15 (Y_01), U16.3 (Y_1)
unnamed: U4.16 (Y_02), U16.4 (Y_2)
unnamed: U4.17 (Y_03), U16.5 (Y_3)
unnamed: U4.18 (Y_04), U16.6 (Y_4)
unnamed: U4.19 (Y_05), U16.7 (Y_5)
unnamed: U4.20 (Y_06), U16.8 (Y_6)
unnamed: U4.21 (Y_07), U16.9 (Y_7)
unnamed: U4.22 (Y_08), U16.10 (Y_8)
unnamed: U4.23 (Y_09), U16.11 (Y_9)
unnamed: U4.24 (Y_010), U16.12 (Y_10)
unnamed: U4.25 (Y_011), U16.13 (Y_11)
POT1_A: IC5.18 (A1), R2.2, U1.14
POT1_W: C2.1, IC5.17 (W1)
POT2_A: IC5.19 (A2), R3.2
POT2_W: C3.1, IC5.20 (W2)
POT3_A: IC5.15 (A3), R8.2
POT3_W: C4.1, IC5.14 (W3)
POT4_A: IC5.22 (A4), R4.2
POT4_W: C5.1, IC5.23 (W4)
POT5_A: IC8.18 (A1), R9.2
POT5_W: C7.1, IC8.17 (W1)
POT6_A: C9.1, IC8.19 (A2), R15.2
POT6_B: C9.2, IC8.21 (B2), R21.1
POT6_W: IC8.20 (W2), R27.1
POT7_A: C10.1, IC8.15 (A3), R14.2
POT7_B: C10.2, IC8.13 (B3), R22.1
POT7_W: C13.1, IC8.14 (W3)
POT8_A: IC8.22 (A4), R13.2
POT8_B: IC8.24 (B4), R23.1
POT8_W: C14.1, IC8.23 (W4)
POT9_A: IC11.18 (A1), R30.2
POT9_B: IC11.16 (B1), R39.1
POT9_W: C27.1, IC11.17 (W1)
POT10_A: C22.1, IC11.19 (A2), R31.2
POT10_B: C22.2, IC11.21 (B2), R40.1
POT10_W: C28.1, IC11.20 (W2)
POT11_A: C21.1, IC11.15 (A3), R32.2
POT11_B: C21.2, IC11.13 (B3), R41.1
POT11_W: IC11.14 (W3), R48.1
POT12_A: C23.1, IC11.22 (A4), R33.2
POT12_B: C23.2, IC11.24 (B4), R42.1
POT12_W: IC11.23 (W4), R49.1
POT13_A: C25.1, IC6.18 (A1), R34.2
POT13_B: C25.2, IC6.16 (B1), R43.1
POT13_W: C29.1, IC6.17 (W1)
POT14_A: IC6.19 (A2), R35.2
POT14_B: IC6.21 (B2), R44.1
POT14_W: C30.1, IC6.20 (W2)
POT15_A: IC6.15 (A3), R36.2
POT15_B: IC6.13 (B3), R45.1
POT15_W: C31.1, IC6.14 (W3)
POT16_A: C26.1, IC6.22 (A4), R37.2
POT16_B: C26.2, IC6.24 (B4), R46.1
POT16_W: C32.1, IC6.23 (W4)
POT17_A: C24.1, IC9.18 (A1), R38.2
POT17_B: C24.2, IC9.16 (B1), R47.1
POT17_W: IC9.17 (W1), R50.1
POT18_A: IC9.19 (A2), R51.1, R52.2, R55.2
POT18_B: IC9.21 (B2), R53.1, R54.2, R56.1
POT19_A: IC9.15 (A3), R55.1
POT19_W: C19.1, IC9.14 (W3)
POT20_A: IC9.22 (A4), R56.2
POT20_W: C39.1, IC9.23 (W4)
PReset_POT: IC5.5 (~PR), IC6.5 (~PR), IC8.5 (~PR), IC9.5 (~PR), IC11.5 (~PR)
SD_POT: IC5.7 (~SHDN), IC6.7 (~SHDN), IC8.7 (~SHDN), IC9.7 (~SHDN), IC11.7 (~SHDN)
SPI1_MOSI: IC5.8 (SDI), IC6.8 (SDI), IC8.8 (SDI), IC9.8 (SDI), IC10.17 (PA7), IC11.8 (SDI), J3.9
SPI1_SCK: IC5.9 (CLK), IC6.9 (CLK), IC8.9 (CLK), IC9.9 (CLK), IC10.15 (PA5), IC11.9 (CLK), J3.10
SPI2_MOSI: IC1.1 (DIN), IC10.28 (PB15), J3.11
SPI2_SCK: IC1.13 (CLK), IC10.21 (PB10), J3.12
SWCLK: IC10.37 (PA14), J19.3
SWDIO: IC10.34 (PA13), J19.2
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

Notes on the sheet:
BASS LIN1
BASS LIN2
MEDIUM LIN2
TREBLE LIN2
MEDIUM LIN1
TREBLE LIN1
LIN1 IN
Line 2 IN
MASTER OUT
MICROFOON VOLUME
L-R
rood
oranje
groen
Component alleen nog bestellen

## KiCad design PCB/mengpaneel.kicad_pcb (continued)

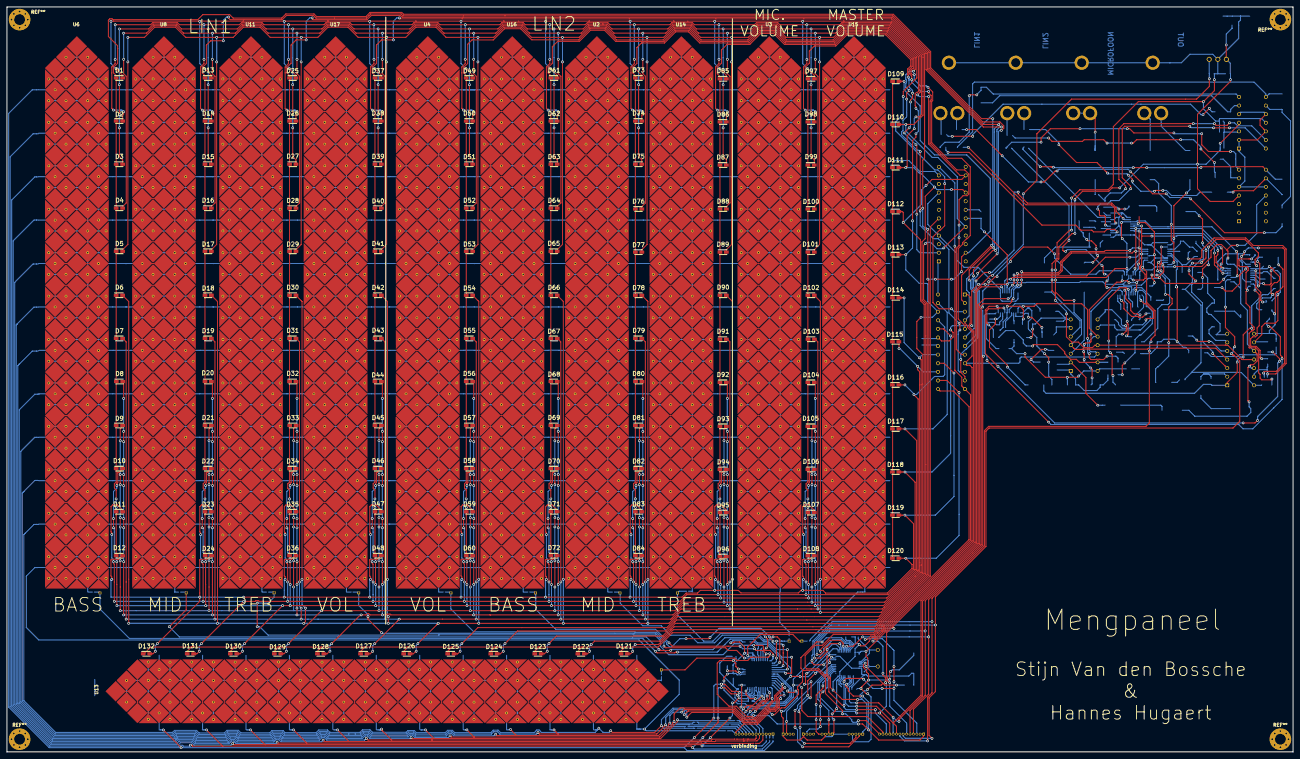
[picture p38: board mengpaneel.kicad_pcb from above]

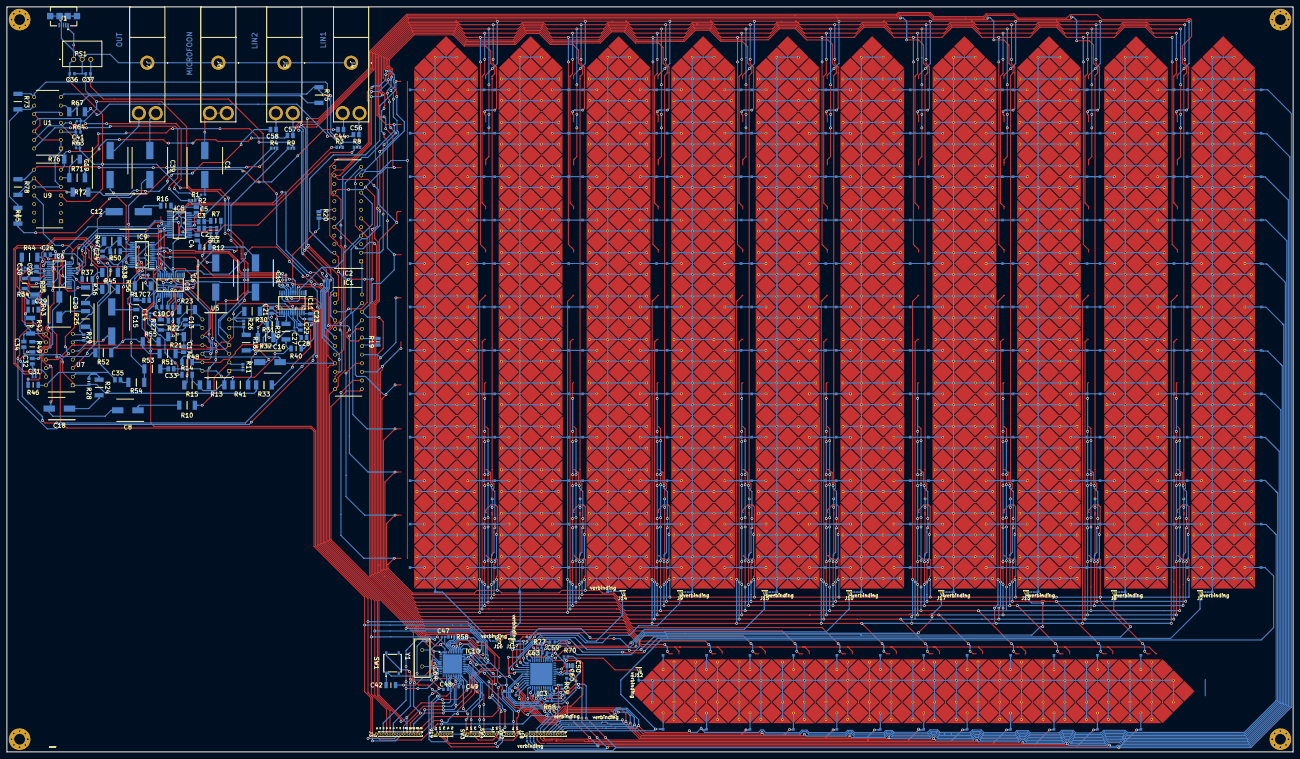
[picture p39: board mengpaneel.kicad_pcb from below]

Board: 2 copper layers, 380.2 x 220.2 mm, 320 parts (176 on the bottom side), 300 nets.

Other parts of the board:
.: Fuse_0201_0603Metric
verbinding: Fuse_0201_0603Metric
verbinding#2, verbinding#3, verbinding#4, verbinding#5, verbinding#6, verbinding#7, verbinding#8, verbinding#9, verbinding#10, verbinding#11, verbinding#12, verbinding#13, verbinding#14, verbinding#15: Fuse_0201_0603Metric

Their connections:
laag_5: verbinding.1, verbinding.2; also elsewhere on the board
laag_6: verbinding#2.1, verbinding#2.2; also elsewhere on the board
laag_9: verbinding#3.1, verbinding#3.2; also elsewhere on the board
laag_10: ..1, ..2; also elsewhere on the board
laag_11: verbinding#4.1, verbinding#4.2; also elsewhere on the board
slider_1: verbinding#15.1, verbinding#15.2; also elsewhere on the board
slider_2: verbinding#14.1, verbinding#14.2; also elsewhere on the board
slider_3: verbinding#11.1, verbinding#11.2; also elsewhere on the board
slider_4: verbinding#9.1, verbinding#9.2; also elsewhere on the board
slider_5: verbinding#7.1, verbinding#7.2; also elsewhere on the board
slider_6: verbinding#13.1, verbinding#13.2; also elsewhere on the board
slider_7: verbinding#5.1, verbinding#5.2; also elsewhere on the board
slider_8: verbinding#10.1, verbinding#10.2; also elsewhere on the board
slider_9: verbinding#8.1, verbinding#8.2; also elsewhere on the board
slider_10: verbinding#6.1, verbinding#6.2; also elsewhere on the board
slider_11: verbinding#12.1, verbinding#12.2; also elsewhere on the board

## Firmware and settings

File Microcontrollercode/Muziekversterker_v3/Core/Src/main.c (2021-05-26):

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
/* Includes ------------------------------------------------------------------*/
#include "main.h"

/* USER CODE BEGIN Includes */
#include <errno.h>
#include <sys/unistd.h>

/* USER CODE END Includes */

/* USER CODE BEGIN PD */

#define TOUCHADRESS_READ 0x4B
#define TOUCHADRESS_WRITE 0x4A
#define TOUCHSCALING_X 372
#define TOUCHSCALING_Y 341
#define POTVALUE_SCALING 23
#define DELAYCOUNT 50


/* USER CODE END PD */


I2C_HandleTypeDef hi2c1;

SPI_HandleTypeDef hspi2;

UART_HandleTypeDef huart1;

void SystemClock_Config(void);
static void MX_GPIO_Init(void);
static void MX_I2C1_Init(void);
static void MX_SPI2_Init(void);
static void MX_USART1_UART_Init(void);
/* USER CODE BEGIN PFP */

void enableInterrupt(void);
void HAL_GPIO_EXTI_Callback(uint16_t);

void initializePeripherals(void);
void initializeLedDriver(void);
void initializeTouchController(void);

void processTouch(void);
uint8_t readTouches(uint8_t[], uint16_t);
void getCoordinatesLastTouch(uint16_t[]);
void writeToTouchController(uint8_t[],uint16_t);

void setLedValues(void);
void writeToLedsRegister(uint8_t[]);

void setPotValues(void);
void writeToPotentiometers(uint8_t[],uint16_t, int);



void __attribute__((naked)) SysTickDelayCount(unsigned long ulCount)
{
    __asm("    subs    r0, #1\n"
          "    bne     SysTickDelayCount\n"
          "    bx      lr");
}

int _write(int file, char *ptr, int len) {
    HAL_StatusTypeDef xStatus;
    switch (file) {
    case STDOUT_FILENO: /*stdout*/
		xStatus = HAL_UART_Transmit(&huart1, (uint8_t*)ptr, len, HAL_MAX_DELAY);
		if (xStatus != HAL_OK) {
			errno = EIO;
			return -1;
		}
        break;
    case STDERR_FILENO: /* stderr */
		xStatus = HAL_UART_Transmit(&huart1, (uint8_t*)ptr, len, HAL_MAX_DELAY);
		if (xStatus != HAL_OK) {
			errno = EIO;
			return -1;
		}
        break;
    default:
        errno = EBADF;
        return -1;
    }
    return len;
}


/* USER CODE END PFP */

/* USER CODE BEGIN 0 */

//Values of leds kept, every value is value from 0-12 for each sliders led array


uint8_t ledValues[11];
uint8_t potValues[20];
uint16_t touchCoordinates[2];
int isTouchInitialized = 0;

/* USER CODE END 0 */

/**
  * @brief  The application entry point.
  * @retval int
  */
int main(void)
{
  /* MCU Configuration--------------------------------------------------------*/

  /* Reset of all peripherals, Initializes the Flash interface and the Systick. */
  HAL_Init();

  /* Configure the system clock */
  SystemClock_Config();

  /* Initialize all configured peripherals */
  MX_GPIO_Init();
  MX_I2C1_Init();
  MX_SPI2_Init();
  MX_USART1_UART_Init();
  /* USER CODE BEGIN 2 */

  //Initialization of Potvalues to 0

  for(int i=0;i<20;i++){
	  potValues[i]=0xFF;
  }

  //L-R balance default op mid zetten
  potValues[17]=128;

  //initialization of LedValues to 0
  for(int i=0;i<11;i++){
	  ledValues[i]=0x00;
  }
  HAL_Delay(50);

  initializePeripherals();


  //led test
  uint8_t data[4];


  initializeLedDriver();


  enableInterrupt();


 HAL_Delay(10);

 setPotValues();

  /* USER CODE END 2 */

  /* Infinite loop */
  /* USER CODE BEGIN WHILE */
  while (1)
  {
    /* USER CODE END WHILE */

    /* USER CODE BEGIN 3 */

	  /*data[0]=0x0F; //LED display test, all on
	      data[1]=0x01;
	      data[2]=0x0F;
	      data[3]=0x01;

	      writeToLedsRegister(data);
	  */


	  initializeLedDriver();

	  data[0]=0x01; //LED display test, all on
	  data[1]=0xFF;
	  data[2]=0x01;
	  data[3]=0xFF;

	  writeToLedsRegister(data);

	  HAL_Delay(200);


  }
  /* USER CODE END 3 */
}

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
/* USER CODE BEGIN 4 */


void enableInterrupt(){
	/* EXTI interrupt init*/
	  HAL_NVIC_SetPriority(EXTI9_5_IRQn, 0, 0);
	  HAL_NVIC_EnableIRQ(EXTI9_5_IRQn);
}

void HAL_GPIO_EXTI_Callback(uint16_t GPIO_Pin){
	printf("interrupt\r\n");

	if(GPIO_Pin == TOUCH_INT_Pin){

		//first time interrupt is generated is for initialization for touchcontroller
		if(!isTouchInitialized){
			initializeTouchController();
			isTouchInitialized = 1;
		}else{

			//interrupt generated by touchcontroller, should read out last touch now
			getCoordinatesLastTouch(touchCoordinates);
			//use touchcoordinates to write to LEDs & pots

			processTouch();
			//converting touchCoordinates to usable values for LEDs & pots

		}
	}
}


void initializePeripherals(){
	HAL_GPIO_WritePin(CS_LEDS_GPIO_Port,CS_LEDS_Pin,GPIO_PIN_SET);
	HAL_GPIO_WritePin(CS_POT1_GPIO_Port,CS_POT1_Pin,GPIO_PIN_SET);
	HAL_GPIO_WritePin(CS_POT2_GPIO_Port,CS_POT2_Pin,GPIO_PIN_SET);
	HAL_GPIO_WritePin(CS_POT3_GPIO_Port,CS_POT3_Pin,GPIO_PIN_SET);
	HAL_GPIO_WritePin(CS_POT4_GPIO_Port,CS_POT4_Pin,GPIO_PIN_SET);
	HAL_GPIO_WritePin(CS_POT5_GPIO_Port,CS_POT5_Pin,GPIO_PIN_SET);

}

void initializeLedDriver(){
	//LED driver (MAX7219)
	uint8_t data[4];

	//set decode mode for both chips to no decode
	data[0]=0x09;
	data[1]=0x00;
	data[2]=0x09;
	data[3]=0x00;
	writeToLedsRegister(data);


	//Intensity setting; register 0x0A
	//by default both set to max intensity, can be adjusted if some are brighter than others
	data[0]=0x0A;
	data[1]=0x0F;
	data[2]=0x0A;
	data[3]=0x0F;
	writeToLedsRegister(data);

	/**scan-limit mode, set to 8 digits for first one, 3 for other one,
	 * for a total of 11 "digits".
	 * Each "digit" represents a slider with leds,
	 * every segment represents a vertical led layer
	 */
	data[0]=0x0B;
	data[1]=0x07;
	data[0]=0x0B;
	data[1]=0x02;
	writeToLedsRegister(data);

	//enabling shutdown register
	data[0]=0x0C;
	data[1]=0x01;		//writing 0x01 to enable
	data[2]=0x0C;
	data[3]=0x01;
	writeToLedsRegister(data);

}



void initializeTouchController(){
	//Touch controller (MTCH6301)

	uint8_t data[5];

	//following guide to initialize component

	//disable touch cmd
	data[0]=0x55;
	data[1]=0x01; //# of bytes to send
	data[2]=0x01; //disable touch cmd
	writeToTouchController(data,3);

	//write parameters --> write to registers

	//RX channels
	data[0]=0x55;
	data[1]=0x04; //# of bytes to send
	data[2]=0x15; //write to register cmd
	data[3]=0x00; //index location (see datasheet registers) 	here: general		: 0x00
	data[4]=0x01; //offset location 							here: RX channels 	: 0x01
	data[5]=0x0B; //value to write 								here: 11 -> 		: 0x0B
	writeToTouchController(data,6);

	//TX channels
	data[0]=0x55;
	data[1]=0x04; //# of bytes to send
	data[2]=0x15; //write to register cmd
	data[3]=0x00; //index location (see datasheet registers) 	here: general		: 0x00
	data[4]=0x02; //offset location 							here: TX channels 	: 0x02
	data[5]=0x0C; //value to write 								here: 12 -> 		: 0x0C
	writeToTouchController(data,6);

	//RX scaling <7:0>
	data[0]=0x55;
	data[1]=0x04; //# of bytes to send
	data[2]=0x15; //write to register cmd
	data[3]=0x00; //index location (see datasheet registers) 	here: general			: 0x00
	data[4]=0x04; //offset location 							here: RX scaling <7:0>	: 0x04
	data[5]=0x45; //value to write 								here: 5957 -> 0x1745 -> : 0x45
	writeToTouchController(data,6);

	//RX scaling <15:8>
	data[0]=0x55;
	data[1]=0x04; //# of bytes to send
	data[2]=0x15; //write to register cmd
	data[3]=0x00; //index location (see datasheet registers) 	here: general			: 0x00
	data[4]=0x05; //offset location 							here: RX scaling <15:8>	: 0x05
	data[5]=0x17; //value to write 								here: 5957 -> 0x1745 -> : 0x17
	writeToTouchController(data,6);

	//TX scaling <7:0>
	data[0]=0x55;
	data[1]=0x04; //# of bytes to send
	data[2]=0x15; //write to register cmd
	data[3]=0x00; //index location (see datasheet registers) 	here: general			: 0x00
	data[4]=0x06; //offset location 							here: TX scaling <7:0>	: 0x06
	data[5]=0x55; //value to write 								here: 5461 -> 0x1555 -> : 0x55
	writeToTouchController(data,6);

	//TX scaling <15:8>
	data[0]=0x55;
	data[1]=0x04; //# of bytes to send
	data[2]=0x15; //write to register cmd
	data[3]=0x00; //index location (see datasheet registers) 	here: general			: 0x00
	data[4]=0x07; //offset location 							here: TX scaling <15:8>	: 0x07
	data[5]=0x15; //value to write 								here: 5461 -> 0x1555 -> : 0x15
	writeToTouchController(data,6);


	//Sensormapping

	uint8_t registermap[12] ={0x00,0x01,0x02,0x03, 0x04,0x05,0x06,0x07, 0x08,0x09,0x0A,0x0B};
	// RX map = {8,7,3,10, 6,1,5,0, 4,9,2}
	uint8_t RX_mapping[11]  ={0x08,0x07,0x03,0x0A, 0x06,0x01,0x05,0x00, 0x04,0x09,0x02};
	// TX map = {13,6,3,2, 4,30,29,28, 7,14,15,16}
	uint8_t TX_mapping[12]  ={0x0D,0x06,0x03,0x02, 0x04,0x1E,0x1D,0x1C, 0x07,0x0E,0x0F,0x10};


	//RX Mapping
	for(int i=0; i<11 ;i++){
		data[0]=0x55;
		data[1]=0x04; 					//# of bytes to send
		data[2]=0x15; 					//write to register cmd
		data[3]=0x01; 					//index location (see datasheet registers) 	here: sensor map RX	: 0x01
		data[4]=registermap[i]; 	  	//offset location 							here: RX map i		: see registermap above
		data[5]=RX_mapping[i]; 			//value to write 							here: RX value i 	: see RX mapping above
		writeToTouchController(data,6);
	}

	//TX Mapping

	for(int i=0; i<12 ;i++){
		data[0]=0x55;
		data[1]=0x04; 					//# of bytes to send
		data[2]=0x15; 					//write to register cmd
		data[3]=0x02; 					//index location (see datasheet registers) 	here: sensor map TX	: 0x02
		data[4]=registermap[i]; 	  	//offset location 							here: TX map i		: see registermap above
		data[5]=TX_mapping[i]; 			//value to write 							here: TX value i 	: see TX mapping above
		writeToTouchController(data,6);
	}




	//Decoding :

	//Flip State
	data[0]=0x55;
	data[1]=0x04; //# of bytes to send
	data[2]=0x15; //write to register cmd
	data[3]=0x30; //index location (see datasheet registers) 	here: decoding		: 0x30
	data[4]=0x02; //offset location 							here: flipstate		: 0x02
	data[5]=0x04; //value to write 								here: 0b100		 	: 0x04
	writeToTouchController(data,6);



	//Possibly extra values to change: subject to change



	//send scan baseline command
	data[0]=0x55;
	data[1]=0x01; //# of bytes to send
	data[2]=0x14; //scan baseline cmd
	writeToTouchController(data,3);


	//enable touch cmd
	data[0]=0x55;
	data[1]=0x01; //# of bytes to send
	data[2]=0x00; //enable touch cmd
	writeToTouchController(data,3);

}




void processTouch(){
	/* no arguments needed, bc all values used and written to
	 * are saved as global variables.
	 * That being:
	 *  touchCoo, ledValues & potValues
	 */

	//printf("Touchcoordinates (x,y)\r\n%x\r\n%x\r\n",touchCoordinates[0],touchCoordinates[1]);
	//depending on these values, needs to be converted into led values & pot values

	//Touchcontroller get values from 0->4096 for both axis

	int i=0; //used to loop
	int j=0;
	uint8_t slider=50; //give a random value that will never be reached
	uint8_t sliderheight=50;


	//checking for slider with loop
	while(i<11 && slider==50){
		if(i*TOUCHSCALING_X < touchCoordinates[0] && touchCoordinates[0] < (i+1) * TOUCHSCALING_X){
			slider = i;
		}
		i++;
	}

	//default value if something went wrong
	if(slider==50){
		slider=0;
	}


	//checking for heightvalue with loop
	while(j<12 && sliderheight ==50){
		if(j*TOUCHSCALING_Y < touchCoordinates[1] && touchCoordinates[1] <(j+1)*TOUCHSCALING_Y){
			sliderheight = j;
		}
		j++;
	}

	//default value if something went wrong
	if(sliderheight==50){
		sliderheight=0;
	}

	printf("Slider: %d \r\n",slider);
	printf("Sliderheight: %d \r\n",sliderheight);




	//Setting LED values to relevant value
	switch(sliderheight){
		case 0:
			ledValues[slider]=0b00000001;
			break;
		case 1:
			ledValues[slider]=0b00000011;
			break;
		case 2:
			ledValues[slider]=0b00000111;
			break;
		case 3:
			ledValues[slider]=0b00001111;
			break;
		case 4:
			ledValues[slider]=0b00011111;
			break;
		case 5:
			ledValues[slider]=0b00111111;
			break;
		case 6:
			ledValues[slider]=0b01111111;
			break;
		case 7:
			ledValues[slider]=0b11111111;
			break;

		//for cases higher, also just write max value
		case 8:
			ledValues[slider]=0b11111111;
			break;
		case 9:
			ledValues[slider]=0b11111111;
			break;
		case 10:
			ledValues[slider]=0b11111111;
			break;
		case 11:
			ledValues[slider]=0b11111111;
			break;

		default:
			ledValues[slider]=0b00000000;
			break;
	}




	//setting potValues to relevant values

	//SLIDERS NOG AAN TE PASSEN!!!! -> naar welke pot meter er relevant is voor welke slider
	switch(slider){
		case 0:		//BASS LINE1 -> POT6 & POT11
			potValues[5]= POTVALUE_SCALING * (uint8_t)sliderheight;
			potValues[10]= POTVALUE_SCALING * (uint8_t)sliderheight;
			break;
		case 1:		//MID LINE1 -> POT7 & POT10
			potValues[6]= POTVALUE_SCALING * (uint8_t)sliderheight;
			potValues[9]= POTVALUE_SCALING * (uint8_t)sliderheight;
			break;
		case 2:		//TREBLE LINE1 -> POT8 & POT9
			potValues[7]= POTVALUE_SCALING * (uint8_t)sliderheight;
			potValues[8]= POTVALUE_SCALING * (uint8_t)sliderheight;
			break;
		case 3:		//VOL LINE1 -> POT2 & POT3
			potValues[1]= POTVALUE_SCALING * (uint8_t)sliderheight;
			potValues[2]= POTVALUE_SCALING * (uint8_t)sliderheight;
			break;
		case 4:		//VOL LINE2 -> POT4 & POT5
			potValues[3]= POTVALUE_SCALING * (uint8_t)sliderheight;
			potValues[4]= POTVALUE_SCALING * (uint8_t)sliderheight;
			break;
		case 5:		//BASS LINE2 ->POT12 & POT17
			potValues[11]= POTVALUE_SCALING * (uint8_t)sliderheight;
			potValues[16]= POTVALUE_SCALING * (uint8_t)sliderheight;
			break;
		case 6:		//MID LINE2 -> POT13 & POT16
			potValues[12]= POTVALUE_SCALING * (uint8_t)sliderheight;
			potValues[15]= POTVALUE_SCALING * (uint8_t)sliderheight;
			break;
		case 7:		//TREBLE LINE2 -> POT14 & POT15
			potValues[13]= POTVALUE_SCALING * (uint8_t)sliderheight;
			potValues[14]= POTVALUE_SCALING * (uint8_t)sliderheight;
			break;
		case 8:		//MIC VOL -> POT1
			potValues[0]= POTVALUE_SCALING * (uint8_t)sliderheight;
			break;
		case 9:		//MASTER OUT -> POT19 & POT20
			potValues[18]= POTVALUE_SCALING * (uint8_t)sliderheight;
			potValues[19]= POTVALUE_SCALING * (uint8_t)sliderheight;
			break;
		case 10:	//BALANCE L-R -> POT18
			potValues[17]= POTVALUE_SCALING * (uint8_t)sliderheight;
			break;
		default:
			//niks doen
			break;

	}




	//Call functions that handle writing to IC's
	setLedValues();
	setPotValues();

}



uint8_t readTouches(uint8_t databuf[], uint16_t amount_bytes_expected){
	/** reads via i2c, can only read when controller throws interrupt
	 *     ------nog aan te passen!!!
	 */
	HAL_I2C_Master_Receive(&hi2c1,TOUCHADRESS_READ,databuf,amount_bytes_expected,50);
	uint8_t bytesToReceive = (uint8_t)(databuf[0]);

	return bytesToReceive;
}


void getCoordinatesLastTouch(uint16_t touchCo[]){
	uint8_t databuf[20];
	readTouches(databuf,6); //6 expected

	/**byte 0 = amount total bytes
	 * byte 1 = TOUCHID, not really relevant
	 * byte 2 = part of touch X coordinate
	 * byte 3 = other part of touch X coordinate
	 * byte 4 = part of touch Y coordinate
	 * byte 5 = other part of touch Y coordinate
	 */

	//writing X out
	touchCo[0] = (((uint16_t)databuf[3])<<7) + ((uint16_t)databuf[2]);

	//writing Y out
	touchCo[1] = (((uint16_t)databuf[5])<<7) + ((uint16_t)databuf[4]);
}

void writeToTouchController(uint8_t data[],uint16_t amountData){
	HAL_I2C_Master_Transmit(&hi2c1,TOUCHADRESS_WRITE,data,amountData,1);
	SysTickDelayCount(DELAYCOUNT);
	//HAL_I2C_Mem_Write(&hi2c1,TOUCHADRESS_WRITE,memAddress,memAddressSize,data,amountData,50);
}






void setLedValues(){
	//Decoding led values to instructions for led drivers

	/* Noticed a flaw in way led-matrix is set up,
	 * will very likely not be possible to drive LEDs of sliders 9,10 or 11,
	 * neither will LED layers 9,10,11 and 12 be drivable.
	 * There will still be LEDs drivable on Sliders 1-8,
	 *  and of those Led layers 1-8
	 *
	 *
	 *  Data stored is in order:
	 *  7:0 (led layers)
	 *  D7,D0,D1,D2, D3,D4,D5,D6
	 */

	/*  looping over different ledsliders
	 *  LedSlider Mapping : see below
	 */

	uint8_t data[4]; //used to write data out
	uint8_t ledSliderMap[8]= {0x01,0x02,0x03,0x04, 0x05,0x06,0x07,0x08};
	for(int ledSlider=0;ledSlider<8;ledSlider++){

		//easiest to write these manually
		uint8_t ledValue=0x00;
		ledValue = ledValue | ( ledValues[ledSlider] & 0b10000000); 		//writing bit 7
		ledValue = ledValue | ((ledValues[ledSlider] & 0b00000001)<<6);		//writing bit 6
		ledValue = ledValue | ((ledValues[ledSlider] & 0b00000010)<<4);		//writing bit 5
		ledValue = ledValue | ((ledValues[ledSlider] & 0b00000100)<<2);		//writing bit 4
		ledValue = ledValue | ( ledValues[ledSlider] & 0b00001000);			//writing bit 3
		ledValue = ledValue | ((ledValues[ledSlider] & 0b00010000)>>2);		//writing bit 2
		ledValue = ledValue | ((ledValues[ledSlider] & 0b00100000)>>4);		//writing bit 1
		ledValue = ledValue | ((ledValues[ledSlider] & 0b01000000)>>6);		//writing bit 0

		data[0]=ledSliderMap[ledSlider];
		data[1]=ledValue;
		data[2]=0x00; //no-op code, second controller doesn't need to display bc of problem noted above
		data[3]=0x00;
		writeToLedsRegister(data);
	}
}


void writeToLedsRegister(uint8_t data[]){
	/**
	 * uses SPI2 of µc
	 * 2 ic are daisychained after each other
	 * CS is active low, so put it high by default
	 *
	 * Both chips are controlled by daisychaining data; each chip needs 16 bit data,
	 * so two 16 bit values are sent after each other, then CS is pulled high
	*/


	HAL_GPIO_WritePin(CS_LEDS_GPIO_Port, CS_LEDS_Pin, GPIO_PIN_RESET);
	HAL_SPI_Transmit(&hspi2,data,4,1);
	HAL_GPIO_WritePin(CS_LEDS_GPIO_Port, CS_LEDS_Pin, GPIO_PIN_SET);
	SysTickDelayCount(DELAYCOUNT);

}



void setPotValues(){
	uint8_t data[2];
	uint8_t addressMap[4]={0b00000000, 0b00000001, 0b00000010, 0b00000011};

	for(int pot=0;pot<5;pot++){
		for(int pot_comp=0;pot_comp<4;pot_comp++){
			data[0]=addressMap[pot_comp];
			data[1]=potValues[pot*4 + pot_comp];
			writeToPotentiometers(data,2,pot+1);
		}
	}
}


void writeToPotentiometers(uint8_t data[], uint16_t amountBytes,  int pot_ic){
	/**
	 * AD5204
	 * uses SPI1 of µc
	 * 5 different pot_ics, each containing 4 potentiometers.
	 * each pot_ic is addressed with corresponding CS_POTx
	 *
	 *  When writing data to pots, only 11 bits are needed.
	 *  3 bits for pot address, 8 bits for value.
	 *  We'll send 2 bytes, first byte send having 5 0's appended first, as they will get shifted out anyway.
	 *
	 *
	 *  No initialization for pots is needed
	 */

	switch(pot_ic)
	{
		case 1:
			HAL_GPIO_WritePin(CS_POT1_GPIO_Port,CS_POT1_Pin, GPIO_PIN_RESET);
			HAL_SPI_Transmit(&hspi2,data,amountBytes,1);
			HAL_GPIO_WritePin(CS_POT1_GPIO_Port,CS_POT1_Pin, GPIO_PIN_SET);
			break;
		case 2:
			HAL_GPIO_WritePin(CS_POT2_GPIO_Port,CS_POT2_Pin, GPIO_PIN_RESET);
			HAL_SPI_Transmit(&hspi2,data,amountBytes,1);
			HAL_GPIO_WritePin(CS_POT2_GPIO_Port,CS_POT2_Pin, GPIO_PIN_SET);
			break;
		case 3:
			HAL_GPIO_WritePin(CS_POT3_GPIO_Port,CS_POT3_Pin, GPIO_PIN_RESET);
			HAL_SPI_Transmit(&hspi2,data,amountBytes,1);
			HAL_GPIO_WritePin(CS_POT3_GPIO_Port,CS_POT3_Pin, GPIO_PIN_SET);
			break;
		case 4:
			HAL_GPIO_WritePin(CS_POT4_GPIO_Port,CS_POT4_Pin, GPIO_PIN_RESET);
			HAL_SPI_Transmit(&hspi2,data,amountBytes,1);
			HAL_GPIO_WritePin(CS_POT4_GPIO_Port,CS_POT4_Pin, GPIO_PIN_SET);
			break;
		case 5:
			HAL_GPIO_WritePin(CS_POT5_GPIO_Port,CS_POT5_Pin, GPIO_PIN_RESET);
			HAL_SPI_Transmit(&hspi2,data,amountBytes,1);
			HAL_GPIO_WritePin(CS_POT5_GPIO_Port,CS_POT5_Pin, GPIO_PIN_SET);
			break;
		default:
			printf("Error\r\n");
			break;

	}
	SysTickDelayCount(DELAYCOUNT);


}







/* USER CODE END 4 */
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


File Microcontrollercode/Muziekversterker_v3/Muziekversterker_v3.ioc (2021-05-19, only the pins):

Mcu.UserName=STM32F746NGHx
PB15.Signal=SPI2_MOSI
PB4.GPIO_Label=CS_POT1
PB4.Signal=GPIO_Output
PB8.Signal=I2C1_SCL
PB9.Signal=I2C1_SDA
PC14/OSC32_IN.Signal=RCC_OSC32_IN
PC15/OSC32_OUT.Signal=RCC_OSC32_OUT
PC6.GPIO_Label=TOUCH_INT
PC6.Signal=GPXTI6
PG6.GPIO_Label=CS_LEDS
PG6.Signal=GPIO_Output
PG7.GPIO_Label=CS_POT2
PG7.Signal=GPIO_Output
PH0/OSC_IN.Signal=RCC_OSC_IN
PH1/OSC_OUT.Signal=RCC_OSC_OUT
PH6.GPIO_Label=CS_POT4
PH6.Signal=GPIO_Output
PI0.GPIO_Label=CS_POT3
PI0.Signal=GPIO_Output
PI1.Signal=SPI2_SCK
PI3.GPIO_Label=CS_POT5
PI3.Signal=GPIO_Output

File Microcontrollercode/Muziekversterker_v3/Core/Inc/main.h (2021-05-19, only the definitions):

#define CS_POT1_Pin GPIO_PIN_4
#define CS_POT1_GPIO_Port GPIOB
#define CS_POT5_Pin GPIO_PIN_3
#define CS_POT5_GPIO_Port GPIOI
#define CS_POT3_Pin GPIO_PIN_0
#define CS_POT3_GPIO_Port GPIOI
#define TOUCH_INT_Pin GPIO_PIN_6
#define TOUCH_INT_GPIO_Port GPIOC
#define TOUCH_INT_EXTI_IRQn EXTI9_5_IRQn
#define CS_POT2_Pin GPIO_PIN_7
#define CS_POT2_GPIO_Port GPIOG
#define CS_LEDS_Pin GPIO_PIN_6
#define CS_LEDS_GPIO_Port GPIOG
#define CS_POT4_Pin GPIO_PIN_6
#define CS_POT4_GPIO_Port GPIOH

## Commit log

2021-03-16 Footprints sliders aangepast + slider links-rechts footprint toegevoegd
    [schema_tp.sch]
2021-03-23 update 23/03/2021 alle libraries aangepast naar definitieve componenten
    [AD5290YRMZ10-R7.stl, AD5290YRMZ10-R7.stp, EDI2CAP.CFG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]
2021-03-23 Added mengpaneel footprint & schema's voor de tweede keer
    [schema_tp.sch]
2021-03-23 associatie footprint associatie footprint
    [mengpaneel.sch]
2021-03-23 Startcode toegevoegd (automatisch gegenereerd door CubeMX) + Paar touchpad footprints toegevoegd (hopelijk geen problemen hiervan)
2021-03-23 23/03/2021 verdere aanpassing
    [mengpaneel.sch]
2021-03-27 tussentijdse vernieuwing 27/03/2021
    [mengpaneel.sch]
2021-04-02 PCB bijna af
    [mengpaneel.kicad_pcb, mengpaneel.sch]
2021-04-04 Ho ho ho vrolijke Pasen iedereen.🐇🧺🥚 pcb bijna af
    [mengpaneel.kicad_pcb]
2021-04-05 PCB af alleen nog wachten op touchsliders
    [mengpaneel.kicad_pcb, mengpaneel.sch]
2021-04-07 PCB af nu wachten op de docenten hun feedback.
    [mengpaneel.kicad_pcb, mengpaneel.sch]
2021-04-08 created PDF versions of KICad schema & PCB, version of 08/04, 16:30
2021-04-08 edited PCB slightly to modify text for Bass - medium - treble
    [mengpaneel.kicad_pcb]
2021-04-15 Kleine foutjes nog aangepast.
    [mengpaneel.kicad_pcb, mengpaneel.sch]
2021-04-15 kleine aanpassing aan PCB
    [mengpaneel.kicad_pcb]
2021-04-15 Document beginnen invullen
    [mengpaneel.kicad_pcb, mengpaneel.sch]
2021-04-17 PCB doet aan alle normen van de docent
    [CR0805-FX-9531ELF.stl, CR0805-FX-9531ELF.stp, mengpaneel.kicad_pcb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]
2021-04-18 Document bij getypt.
    [mengpaneel.kicad_pcb]
2021-04-20 word in git steken.
    [mengpaneel.kicad_pcb, mengpaneel.sch]
2021-04-20 initialisaties SPI functies
2021-04-20 pcb oke
    [mengpaneel.kicad_pcb, mengpaneel.sch]
2021-04-27 added basic SPI & I2C write/read commands
2021-05-04 Extra functionaliteit I2C toegevoegd om op verder te werken
2021-05-04 Word document aangepast
    [mengpaneel.kicad_pcb, mengpaneel.sch]
2021-05-07 Led controller code aangevuld, mogelijks probleem met leds aan te sturen, te testen
2021-05-10 Een stuk van het gebruikte componenten een beetje herschreven en spelfouten gecorrigeerd.
2021-05-17 enkele kleine bugfixes en aanpassingen
    [main.c]
2021-05-17 added leddisplaydriver code
2021-05-18 Conversie toegevoegd om touchwaarden om te zetten naar bruikbare pot-values & ledvalues
2021-05-19 Version 3 v microcontrollercode, deze is geschreven voor STM32F746G-DISCO bordje (EMSYS-bordje)

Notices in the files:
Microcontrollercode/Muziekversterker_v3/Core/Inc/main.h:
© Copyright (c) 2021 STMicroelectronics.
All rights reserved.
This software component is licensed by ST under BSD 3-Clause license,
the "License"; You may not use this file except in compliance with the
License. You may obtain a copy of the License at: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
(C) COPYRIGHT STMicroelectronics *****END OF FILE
